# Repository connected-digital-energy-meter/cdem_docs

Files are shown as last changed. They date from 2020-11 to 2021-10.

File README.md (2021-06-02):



# Connected Digital Energy Meter

Connected Digital Energy Meter documentation for the PWO project IoT opportunities.

## Development

First time use:

```bash
npm install
```

To run local VuePress instance:

```bash
npm run docs:dev
```

Then navigate to [http://localhost:8080](http://localhost:8080) in your browser.

## Emojis

Find them on [https://emojipedia.org/](https://emojipedia.org/).

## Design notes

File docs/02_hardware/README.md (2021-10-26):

# Hardware

The **CDEM - Connected Digital Energy Meter** device is a standalone PCB that can be directly connected to a Belgian digital electricity meter. It can then read the P1 port of the digital meter and send that information to an MQTT broker.

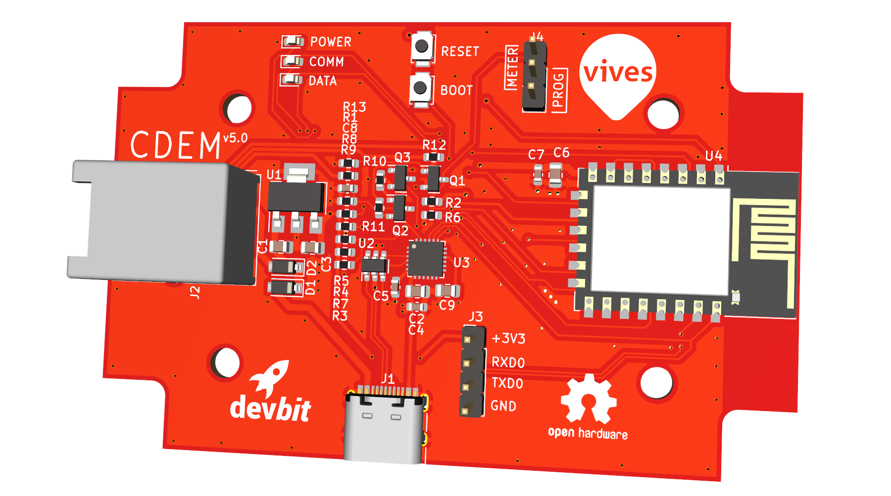
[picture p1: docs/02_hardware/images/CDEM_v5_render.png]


::: tip 🎉 Standalone PCB
The newer versions of the PCB (v4.0 and up) are stand-alone devices and require no external power supply. They draw their energy from the digital meter.
:::

All hardware is open source and can be modified to fit your own needs. Feel free to download the [KiCad project files](https://github.com/connected-digital-energy-meter/cdem-hardware) at Github.

## Ordering Your Own CDEM

Due to the number of small components we advice you to order an assembled PCB, rather then solder it yourself.

When ordering your PCB you will need to upload the following information:

* Gerber files: [Github](https://github.com/connected-digital-energy-meter/cdem-hardware/tree/master/gerber)
* Bill of Material: [Github](https://github.com/connected-digital-energy-meter/cdem-hardware/tree/master/assembly)

### Suppliers

We can advice the following suppliers :

* [JLCPCB](https://jlcpcb.com/)
<figure class="video_container">
  <iframe src="https://jlcpcb.com/video/place.v2.mp4" frameborder="0" allowfullscreen="true"> </iframe>
</figure>
* [ALLPCB](https://www.allpcb.com/)
* [PCBWay](https://www.pcbway.com/)

## RJ12 Cable

Connecting the Connected Digital Energy Meter to the Fluvius Digital meter requires an RJ12 cable with 6 internal wires.

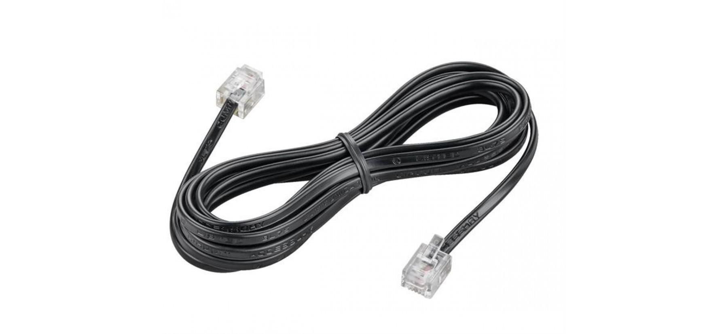
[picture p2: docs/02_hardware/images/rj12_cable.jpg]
RJ12 Cable


When ordering cables one of the cheapest distributors with the wides range of products is [AlleKabels](https://www.allekabels.nl/rj12-kabel/7400/1181351/telefoonkabel-rj12.html). You can choose the length according to your setup.

::: warning 🕵️ Check Connections
Make sure that the RJ12 cable has 6 wires and that both sides have the wires in the same order.
:::

## Casing

To safely take your Connected Digital Energy Meter in operation we recommend putting it into a decent casing. This protects the PCB from dust and such and also makes sure the electronics cannot be short circuited by accident.

A case that fits is the [1591XXM from HAMMOND](http://www.hammondmfg.com/pdf/1591XXM.pdf).

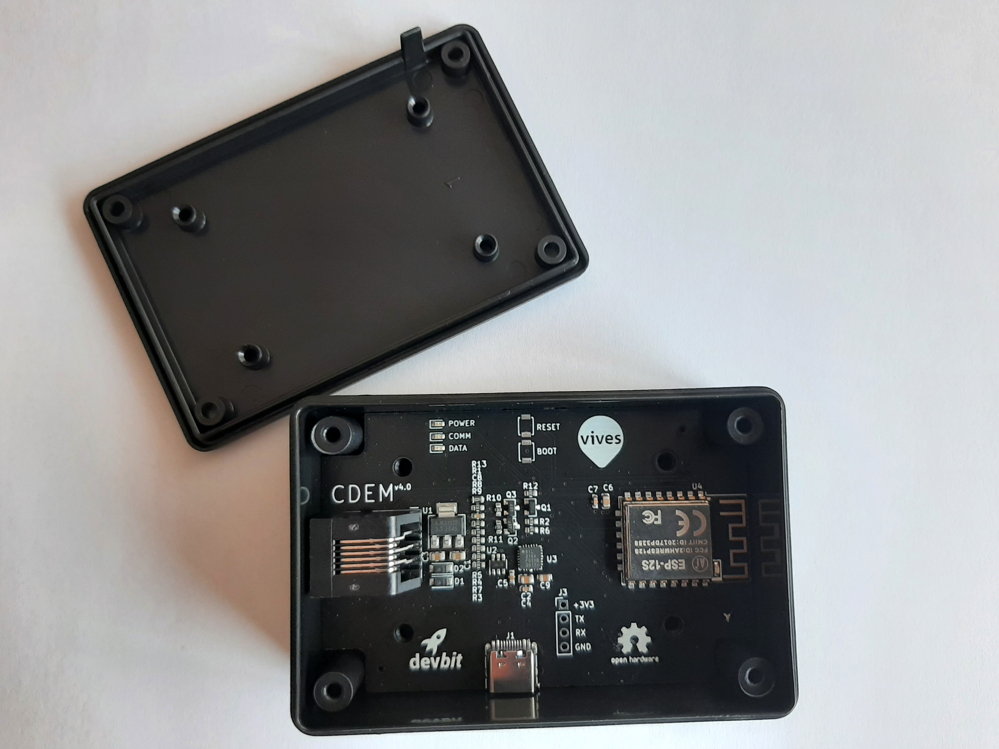
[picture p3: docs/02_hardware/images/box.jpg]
Casing


<!-- TODO - Photo of latest PCB inside case -->

You can order this case on [Conrad](https://www.conrad.be/p/hammond-electronics-1591xxmsbk-1591xxmsbk-universele-behuizing-85-x-56-x-25-abs-zwart-1-stuks-485622).

You will need to make a small adjustment to the box. A small opening will need to be made in the box for the RJ12 connector. You can do this using a small saw or cutter.

<!-- TODO - Photo of latest PCB inside case with cut hole on side -->

If you wish you can mount the PCB inside the case using 4 small 1/4" self-tapping screws, but it is not a requirement.

### 3D Printing Case

If you have a 3D printer at your disposal you can also 3D print your own case.

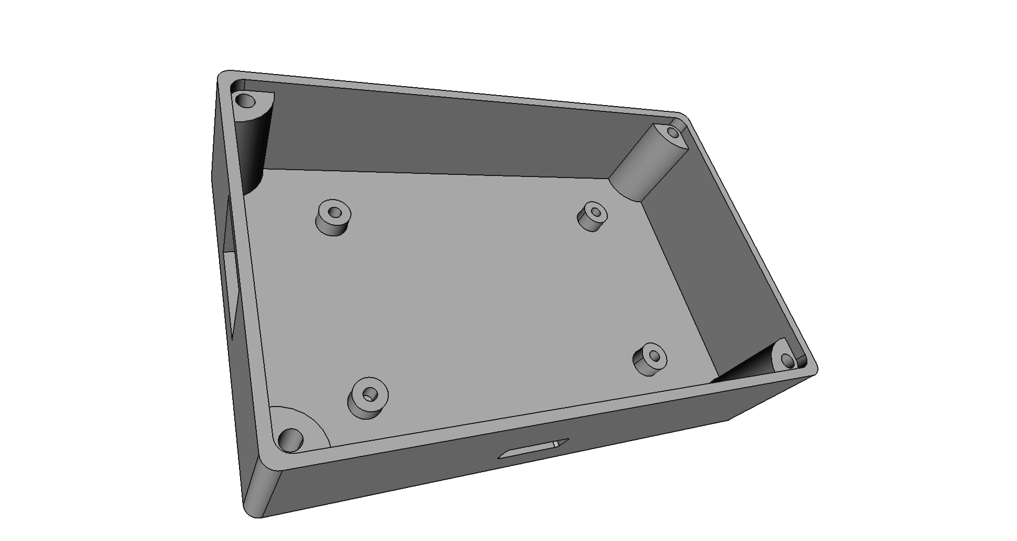
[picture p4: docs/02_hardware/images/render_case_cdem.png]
Render CDEM Case


[CDEM - Casing](https://github.com/connected-digital-energy-meter/cdem-case) is a [FreeCAD](https://freecadweb.org) drawing that contains a basic case which can be easily 3D printed. Feel free to alter it as you wish.

<!-- TODO - Picture of our case -->

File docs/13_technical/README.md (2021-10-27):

# Technical information

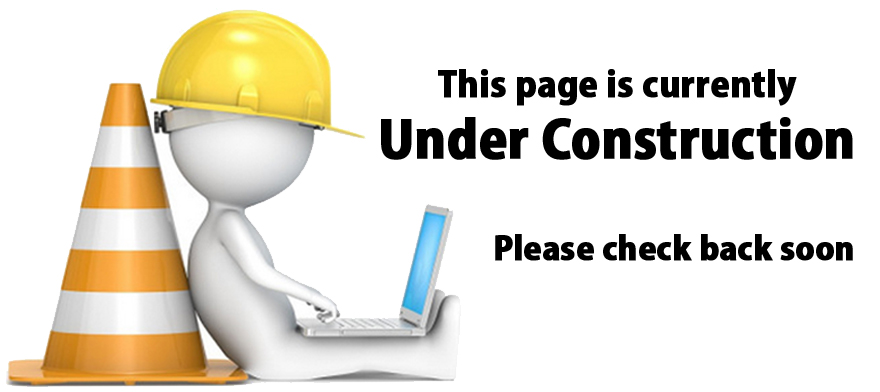
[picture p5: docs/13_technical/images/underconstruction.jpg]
UNDER CONSTRUCTION


## What information is provided with the P1 port ?

The P1 port follows the [DSMR 5 standard](/files/dsmr5.pdf) of the Dutch Smart Meter, extended with the [e-Mucs specification](/files/emucs.pdf).

::: tip S1 Port
The Fluvius digital meter also has an S1 port. This user port (S1) is designed to provide "raw" data to an application (CEMS) at a particularly high frequency. The application must further process this "raw" data to make advanced calculations allowing for very detailed consumption feedback and control.
:::

### Physical connection

The `P1` port is a serial interface that uses a standard RJ12 connector.

::: tip RJ11 vs RJ12
The only difference between RJ11 and RJ12 is in how they are wired and the number of the wires that are being used. RJ12 is a 6P6C wiring standard. RJ11 is a 6P4C wiring standard and only has four wires connected and the remaining two slots are no longer used.
:::

For the CDEM device we need a **RJ12 cable** because we use the digital meter as power source.

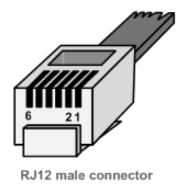
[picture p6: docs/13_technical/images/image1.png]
RJ12 Pinout


| Pin | Signal name |
| :---: | --- |
| 1 | + 5V (Power supply) |
| 2 | Data request |
| 3 | Data GND (ground) |
| 4 | Not connected |
| 5 | Data |
| 6 | GND (ground) |

**Safety**

In order to protect both the user and the Fluvius digital meter, the `P1` port is galvanically isolated from the mains.

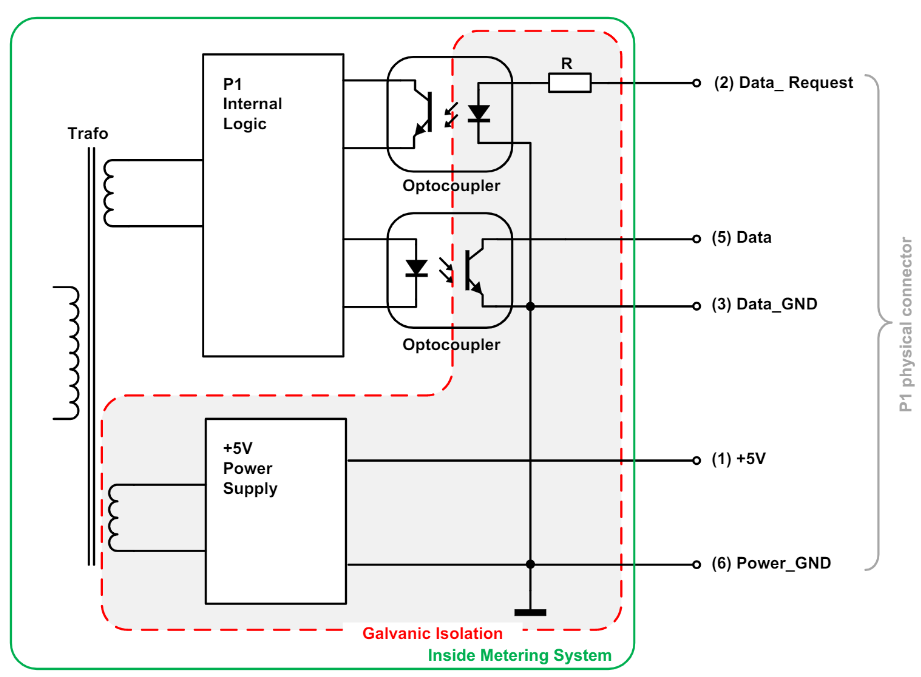
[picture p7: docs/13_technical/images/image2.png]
Port Schematic


#### Power supply

The `P1` interface provides a stable `+5V DC` power supply via `pin 1` (5V) and `pin 6` (GND) to provide a connected IoT device with a power source.

U = 5,0 V ( max = 5,5 V with I = 0 mA , min = 4,9 V with I = 250 mA )

Here we run into our first problem. The maximum output for the power supply is 250 mA which is at the limit for booting a ESP12 chipset.

#### Data request

The P1 port is activated (will start sending data) by setting "Data request" (pin 2) high (4,0V to 5,5V). While receiving data, this line must be kept high.

::: warning Warning
To stop receiving data the "Data request" line must be put in a high impedance mode and must not be connected to the GND or 0V
:::

#### Data

Here we run into our second problem. Due to the use of opto couplers, the "Data" (pin 5) line must be designed as an **Open Collector** output and must be **logically inverted** before it can be used with IoT device ( Raspberry Pi, ESP12, Arduino, ...).

A "Data" line LOW has a voltage of 0,2 V (0 - 1V), HIGH has a voltage of 5,0V with a maximum current of 30 mA.

The solution is either to use a pre-made cable like for instance [this one](https://www.sossolutions.nl/slimme-meter-kabel), or to provide the signal inversion yourself.

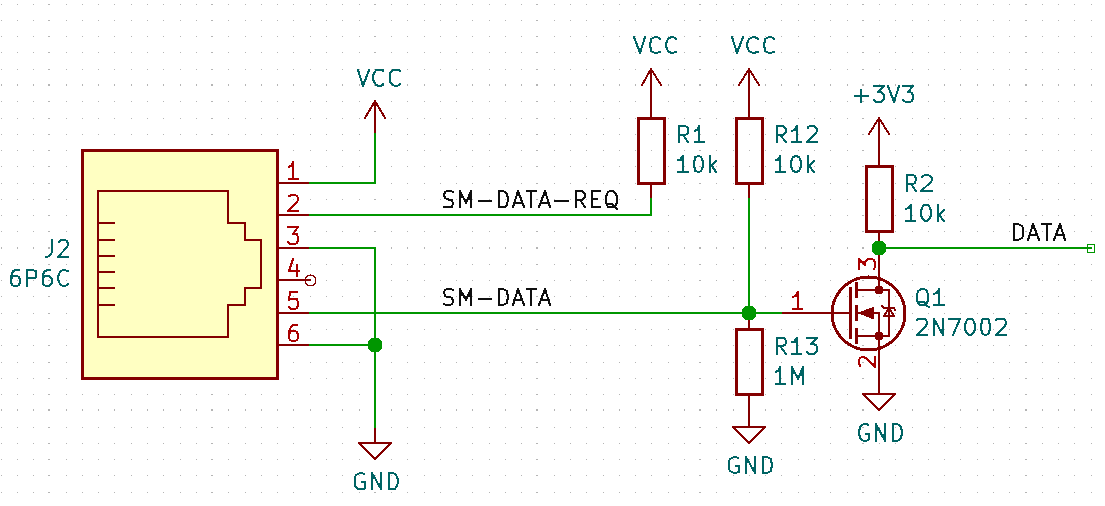
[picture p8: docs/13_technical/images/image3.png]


### Communication protocol

Here we run into our third problem. The P1 communication protocol of a Fluvius Smart Meter is based on the DSMR 5 standard used in the Netherlands but extended with the e-Mucs specifications. Therefore all solutions found on the internet for the Netherlands are not applicable for the Fluvius Smart Meter.

#### Transfert speed and character formatting

The interface must use a fixed transfer speed of 115200 baud. 

::: warning ❗ Cable length restriction
Due to the 115200 baud-rate the max. cable length for this serial communication is 2,5 m.
:::

The Fluvius Smart Meter sends its data to the connected IoT device every single second and the transmission of the entire P1 telegram is completed within 1s.

The format of transmitted data is defined as “8N1”. Namely:

- 1 start bit,
- 8 data bits,
- no parity bit and
- 1 stop bit.

#### Data readout

The Fluvius Smart Meter transmits the data message, as described below, immediately following the activation through the Request signal.



#### End of transmission

The data transmission is complete after the data message has been transmitted. An acknowledgement signal is not provided for.

#### Data objects

For more information on the OBIS codes see the [DSMR 5 standard](/files/dsmr5.pdf) and [e-Mucs specification](/files/emucs.pdf).

##### Electricity data

| OBIS reference | Value | Example |
|---|---|---|
| 0-0:96.1.1 | Equipment identifier | 0-0:96.1.1(4B384547303034303436333935353037) |
| 1-0:1.8.1 | Meter Reading electricity consumption (normal tariff) in 0,001 kWh | 1-0:1.8.1(123456.789*kWh) |
| 1-0:1.8.2 | Meter Reading electricity consumption (low tariff) in 0,001 kWh | 1-0:1.8.2(123456.789*kWh) |
| 1-0:2.8.1 | Meter Reading electricity injected (normal tariff) in 0,001 kWh | 1-0:2.8.1(123456.789*kWh) |
| 1-0:2.8.2 | Meter Reading electricity injected (low tariff) in 0,001 kWh | 1-0:2.8.2(123456.789*kWh) |
| 0-0:96.14.0 | Tariff indicator electricity. **(1=normal, 2=low)** | 0-0:96.14.0(0002) |
| 1-0:1.7.0 | Actual electricity power consumption in 1 Watt resolution | 1-0:1.7.0(01.193*kW) |
| 1-0:2.7.0 | Actual electricity power injected in 1 Watt resolution | 1-0:2.7.0(00.000*kW) |
| 0-0:96.7.21 | Number of power failures in any phases | 0-0:96.7.21(00004) |
| 0-0:96.7. 9 | Number of long power failures in any phases | 0-0:96.7.9(00002) |
| 1-0:99:97.0 | Power failure event log | 1-0:99.97.0(2)(0-0:96.7.19)(101208152415W)(0000000240*s)(101208151004W)(0000000301*s) |
| 1-0:32.32.0 | Number of voltage sags in phase L1 | 1-0:32.32.0(00002) |
| 1-0:52.32.0 | Number of voltage sags in phase L2 | 1-0:52.32.0(00001) |
| 1-0:72.32.0 | Number of voltage sags in phase L3 | 1-0:72.32.0(00000) |
| 1-0:32.36.0 | Number of voltage swells in phase L1 | 1-0:32.36.0(00000) |
| 1-0:52.36.0 | Number of voltage swells in phase L2 | 1-0:52.36.0(00003) |
| 1-0:72.36.0 | Number of voltage swells in phase L3 | 1-0:72.36.0(00000) |
| 1-0:32.7.0 | Instantaneous voltage L1 | 1-0:32.7.0(220.1*V) |
| 1-0:52.7.0 | Instantaneous voltage L2 | 1-0:52.7.0(220.2*V) |
| 1-0:72.7.0 | Instantaneous voltage L3 | 1-0:72.7.0(220.3*V) |
| 1-0:31.7.0 | Instantaneous current L1 | 1-0:31.7.0(001*A) |
| 1-0:51.7.0 | Instantaneous current L2 | 1-0:51.7.0(002*A) |
| 1-0:71.7.0 | Instantaneous current L3 | 1-0:71.7.0(003*A) |
| 1-0:21.7.0 | Instantaneous active power consumption L1 | 1-0:21.7.0(01.111*kW) |
| 1-0:41.7.0 | Instantaneous active power consumption L2 | 1-0:41.7.0(02.222*kW) |
| 1-0:61.7.0 | Instantaneous active power consumption L3 | 1-0:61.7.0(03.333*kW) |
| 1-0:22.7.0 | Instantaneous active power injected L1 | 1-0:22.7.0(04.444*kW) |
| 1-0:42.7.0 | Instantaneous active power injected L2 | 1-0:42.7.0(05.555*kW) |
| 1-0:62.7.0 | Instantaneous active power injected L3 | 1-0:62.7.0(06.666*kW) |
| 0-0:96.3.10 | Breaker state | 0-0:96.3.10(1) |
| 0-0:17.0.0 | Limiter treshold | 0-0:17.0.0(123.4*kW) |
| 1-0:31.4.0 | Fuse supervision threshold (L1) | 1-0:31.4.0(001*A) |

::: warning 🔥 Belgian vs Dutch meter
The Obis-references for High and Low tarif are switched for the Belgian meter compared to the Dutch meter!
**(1 = normal tarif , 2 = low tarif)**
:::

##### Messages

| OBIS reference | Value | Example |
|---|---|---|
| 0-0:96.1.4 | Version information | 0-0:96.1.4(50) |
| 0-0:96.13.0 | Text message max 1024 characters. | 0:96.13.0(303132333435363738393A3B3C3D3E3F3031) |
| 0-0:96.13.1 | Consumer message code | 0-0:96.13.1(3031203631203831) |

##### Gas data

| OBIS reference | Value | Example |
|---|---|---|
| 0-n:24.1.0 | Device-Type | 0-1:24.1.0(003) |
| 0-n:96.1.0 | Equipment identifier | 0-1:96.1.0(3232323241424344313233343536373839) |
| 0-n:24.2.1 | Last 5-minute value (temperature converted), gas delivered to client in m3, including decimal values and capture time | 0-1:24.2.1(101209112500W)(12785.123*m3) |
| 0-n:96.1.1 | M-Bus Device ID 2 |  0-1:96.1.1(3232323241424344313233343536373839) |
| 0-n:24.4.0 | Valve state | 0-1:24.4.0(1) |
| 0-n:24.2.3 | Last value of ‘not temperature corrected’ gas volume in m³, including decimal values and capture time | 0-1:24.2.3(101209112500W)(12785.123*m3) | 

##### Thermal data

| OBIS reference | Value | Example |
|---|---|---|
| 0-n:24.1.0 | Device-Type | 0-1:24.1.0(003) |
| 0-n:96.1.0 | Equipment identifier | 0-1:96.1.0(3232323241424344313233343536373839) |
|  0-n:24.2.1 | Last 5-minute Meter reading Heat or Cold in 0,01 GJ and capture time | 0-1:24.2.1(12.34*GJ) |

##### Water data

| OBIS reference | Value | Example |
|---|---|---|
| 0-n:24.1.0 | Device-Type | 0-1:24.1.0(003) |
| 0-n:96.1.0 | Equipment identifier | 0-1:96.1.0(3232323241424344313233343536373839) |
| 0-n:24.2.1 | Last 5-minute Meter reading in 0,001m3 and capture time | 0-1:24.2.1(12785.123*m3) |

::: warning 🔥 Warning
Be aware of the fact that the number of OBIS codes and the order of them is not fixed. Therefore the connected IoT device must be able to interpret the P1 telegram.
:::

## How is the hardware build ? 

### Version 1

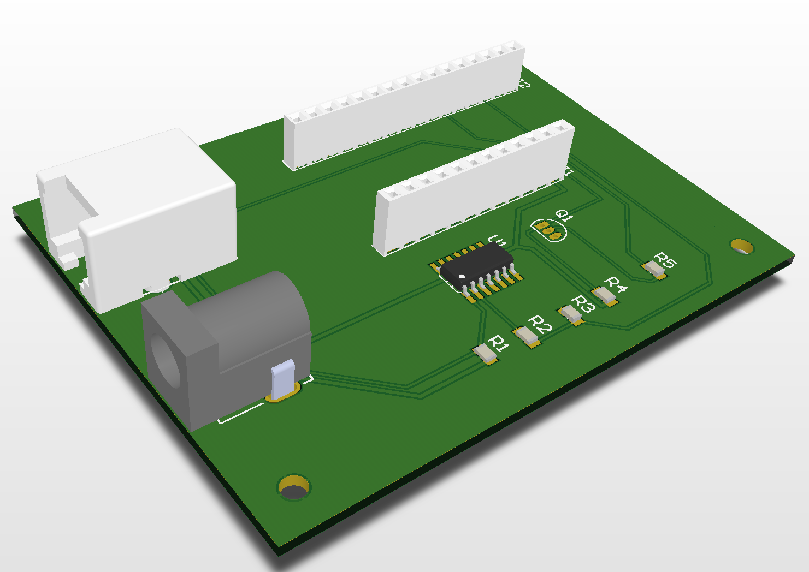
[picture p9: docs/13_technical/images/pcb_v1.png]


This is our [first prototype model](https://workspace.circuitmaker.com/Projects/Details/RonnyMees/FluviusMeterv1) to establish proof of concept, being able to read the P1 telegram from the Fluvius Digital Meter.

This pcb works in conjunction with the [Feather Huzzah 32](https://learn.adafruit.com/adafruit-huzzah32-esp32-feather).

### Version 2

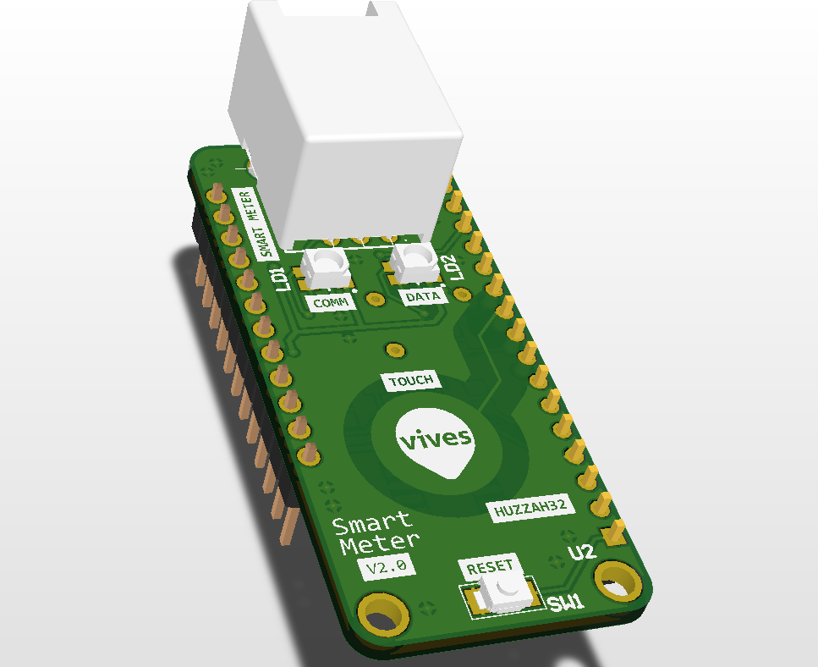
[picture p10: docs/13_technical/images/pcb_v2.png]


This is our [second prototype model](https://workspace.circuitmaker.com/Projects/Details/Nico-De-Witte/cdem) to establish proof of concept, provide a fully functional device that reads the P1 telegram from the Fluvius Digital Meter and publishes it toe a MQTT broker.

This pcb works in conjunction with the [Feather Huzzah 32](https://learn.adafruit.com/adafruit-huzzah32-esp32-feather).

### Version 3

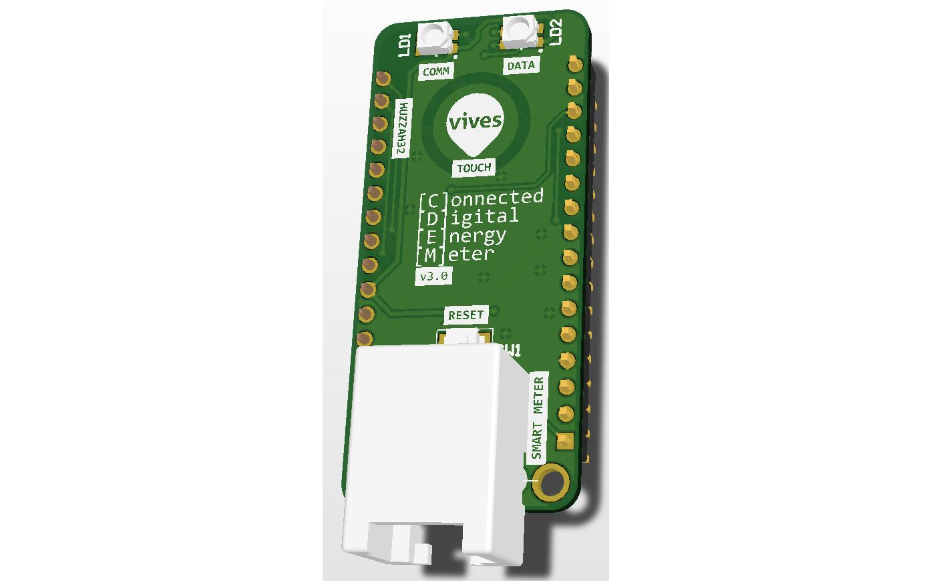
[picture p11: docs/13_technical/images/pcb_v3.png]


In the previous version the usb connector and the RJ12 connector where on opposite sides, therefore we made a [third prototype model]() that was a mirrored version of the second version. This model was never made.

This pcb works in conjunction with the [Feather Huzzah 32](https://learn.adafruit.com/adafruit-huzzah32-esp32-feather).

### Version 4

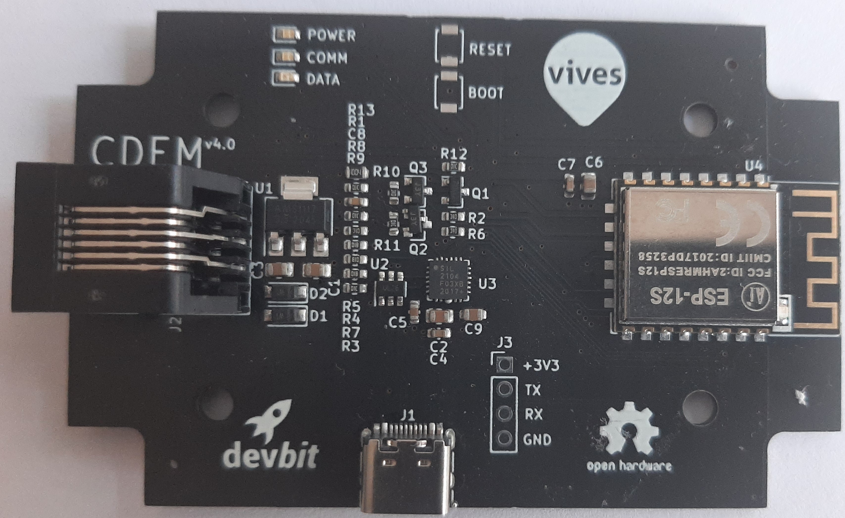
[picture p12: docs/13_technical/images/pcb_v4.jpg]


During a meeting with Fluvius we decided to build a new version that could work standalone (with the power provided by the Fluvius Digital Meter). Due to the powerlimitations we had to rethink our concept and look for low power consuming components to be able to build that [fourth prototype model](https://github.com/connected-digital-energy-meter/cdem-hardware).

### Version 5

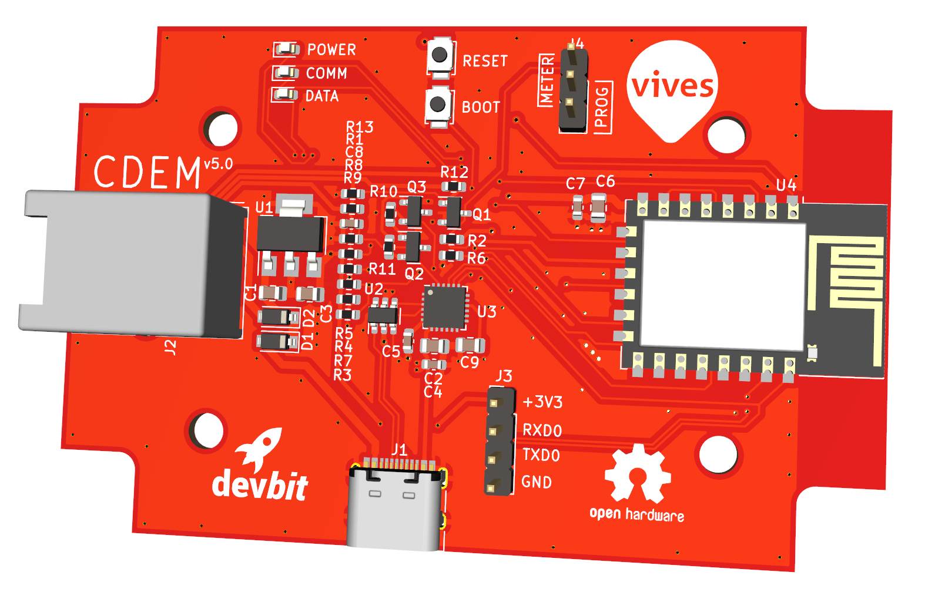
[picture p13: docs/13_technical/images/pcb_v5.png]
PCB v5


<!-- TODO : Github link toevoegen -->
Due to some power issue's and a fault we discoverd in the previous prototype we made a final version that solves this issue.

For the production version we provide some build information of the pcb.

**1. Connection to the Fluvius Meter**



We use the power supply provided from the Fluvius Meter (pin 1). The maximum output is 250 mA which is at the limit of what we need for our ESP12.
:::danger 🔌 Limited Power supply
Should your CDEM experience power problems and reboots often, then we advice to use an external USB power supply.
:::

**2. USB connection and UART bridge**

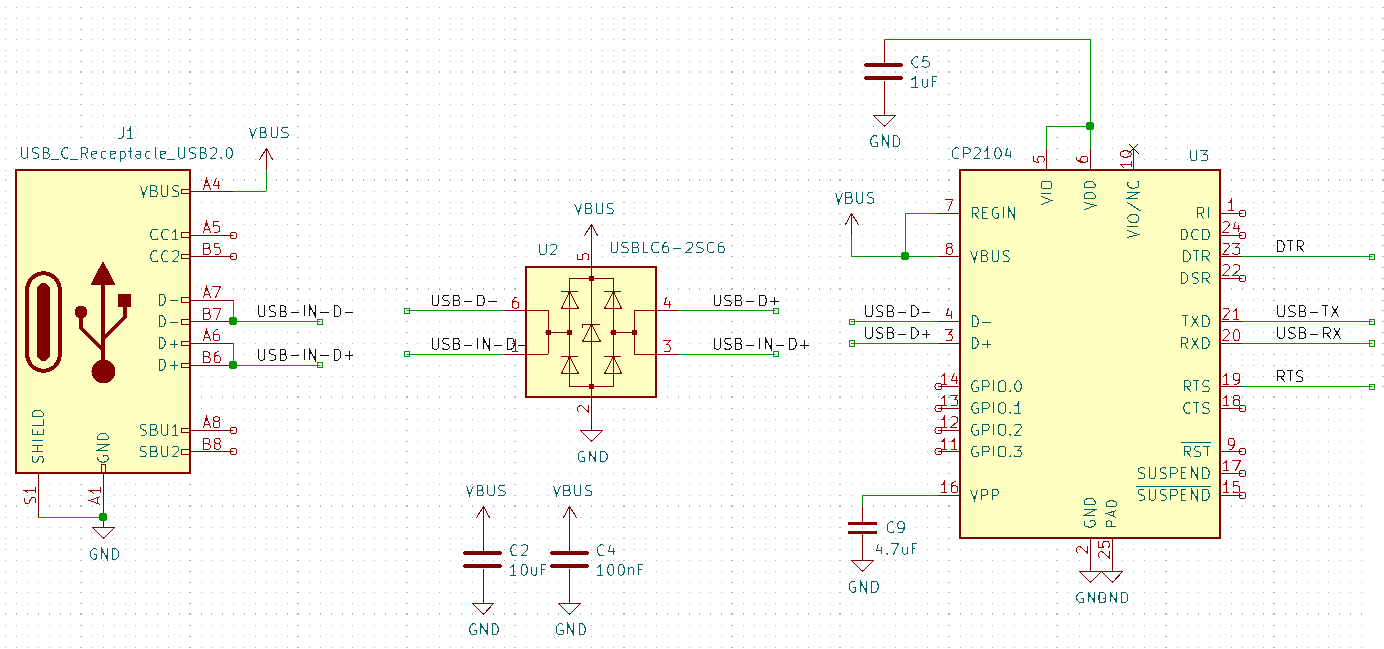
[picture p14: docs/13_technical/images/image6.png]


We have provided a usb connection on the PCB in order to be able to load the firmware via a UART bridge and provide a external power supply if necessary.

**3. Voltage regulator 5V to 3.3V**

<!--TODO: dit moet mogelijks nog aangepast worden naar een nieuwe versie -->

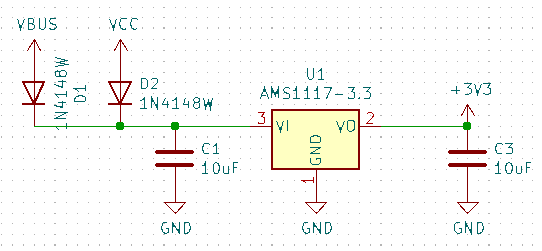
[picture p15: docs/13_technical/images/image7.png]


We have provided a voltage regulator that provides the board of 3.3V.

**4. Processor**

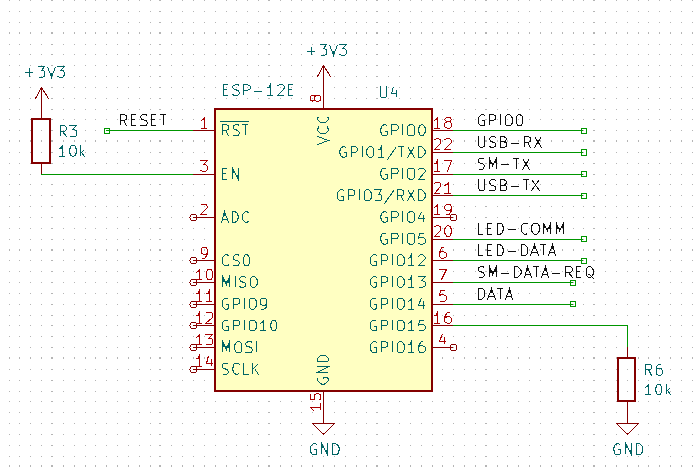
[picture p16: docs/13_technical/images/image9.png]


The heart of the board is a ESP-12E chipset that provides us with a processor and wifi module.

**5. Extra**

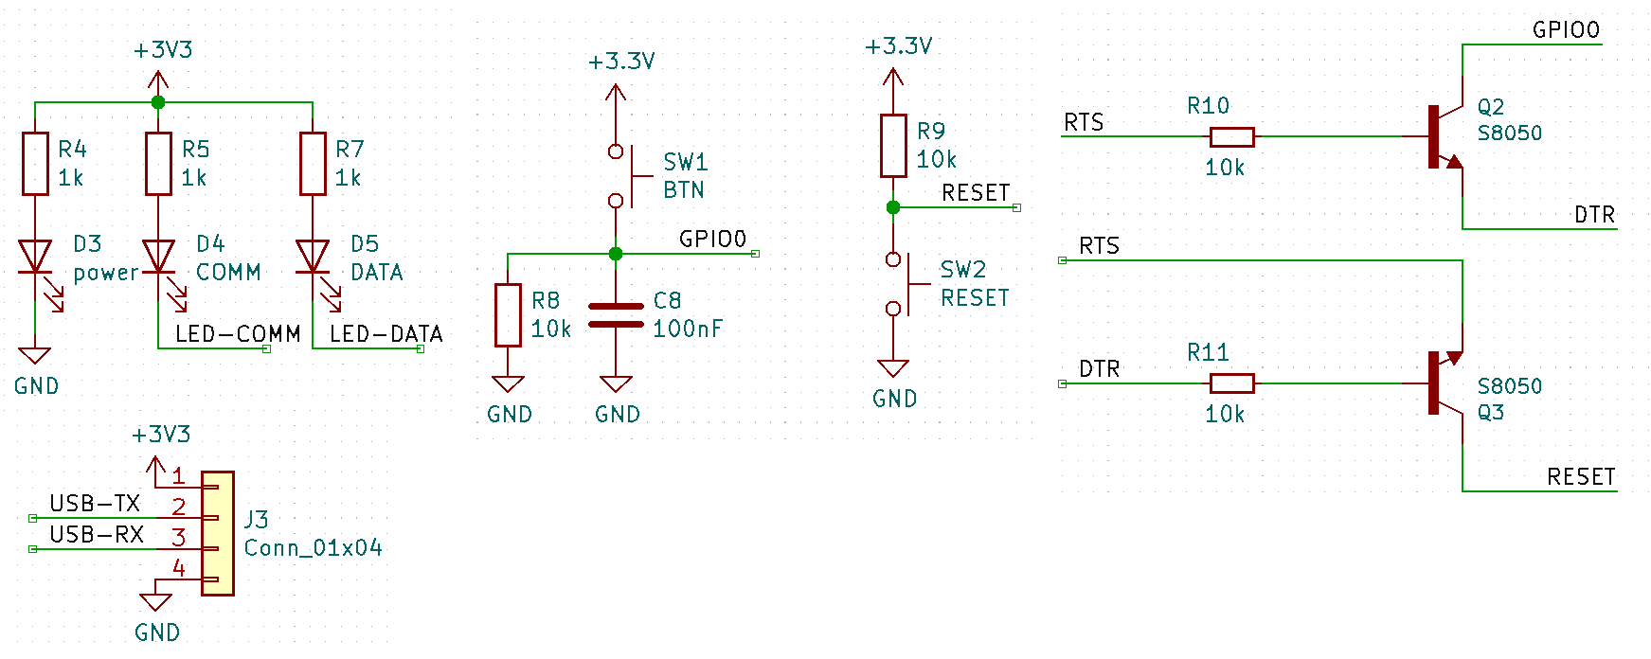
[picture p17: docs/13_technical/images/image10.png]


Finaly we also provided some small circuits for communication led's, push buttons and a jumper.

## How is the firmware build ? 

<!-- TODO: Hier komt de onwikkelinfo van de firmware -->

This flowchart explains the program structure of the firmware.

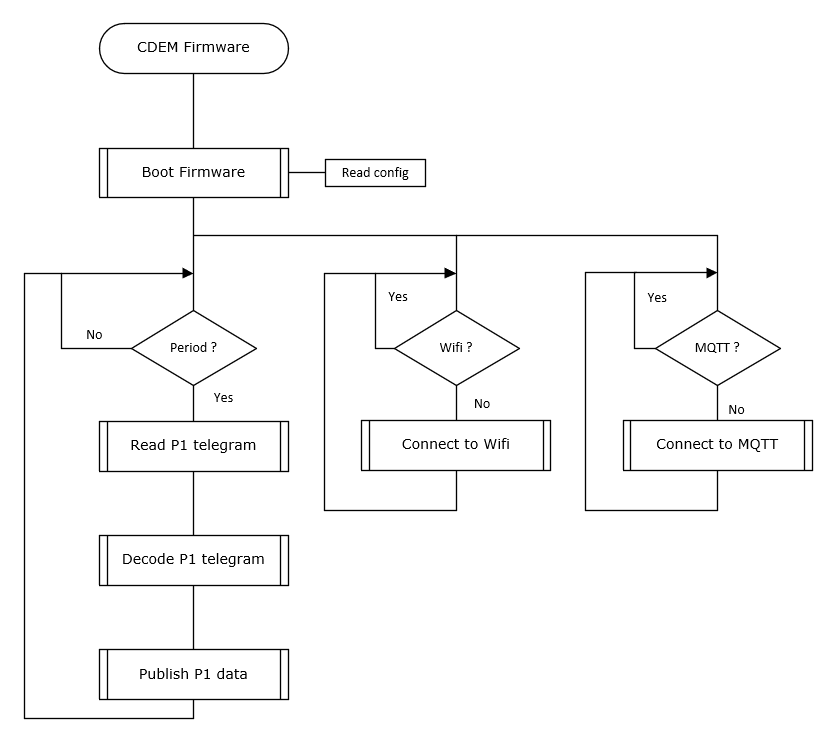
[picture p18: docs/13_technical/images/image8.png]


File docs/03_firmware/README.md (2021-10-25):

# Firmware

Now that you have your CDEM PCB, it is time to upload the firmware into the ESP12 chipset.

Connect the PCB to your computer using a USB-C cable and follow the guide below to flash the device with the latest firmware.

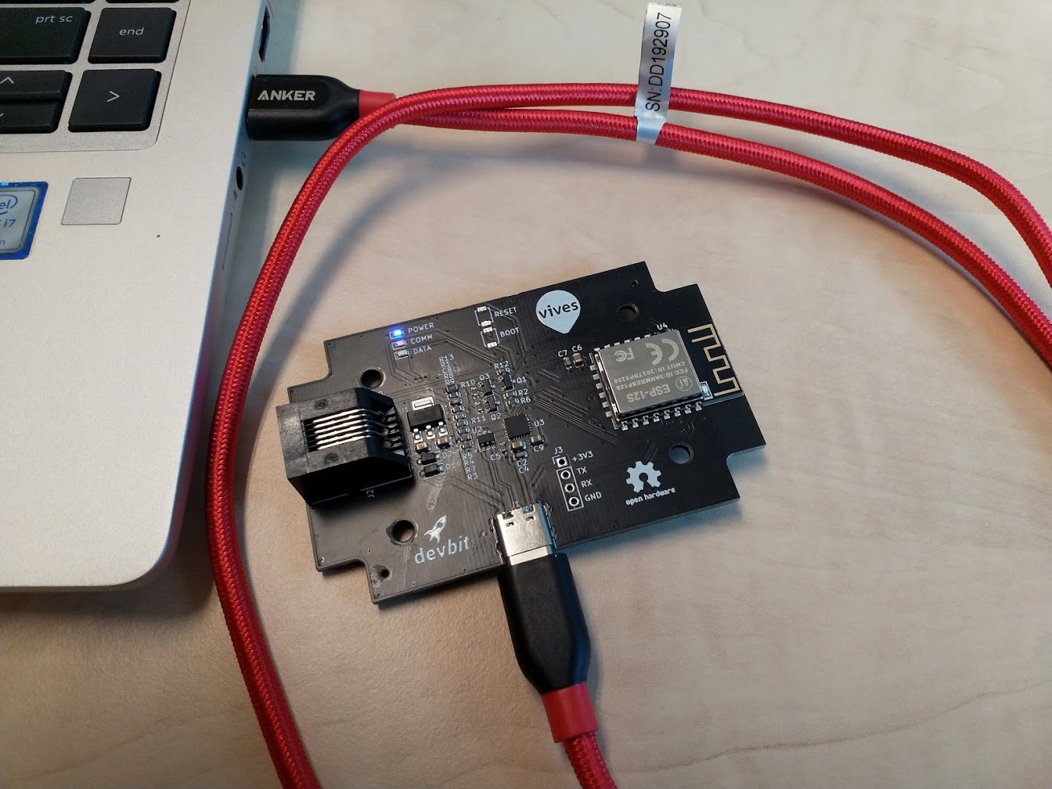
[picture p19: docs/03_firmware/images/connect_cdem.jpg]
Connect CDEM


## Install Arduino IDE

In order to compile and flash the firmware for your CDEM device, you will need to install Arduino IDE.

Instructions on how to install this IDE for most operating systems can be found on the website of [Arduino](https://www.arduino.cc/en/Guide) itself.

Once installed, start the IDE to continue.

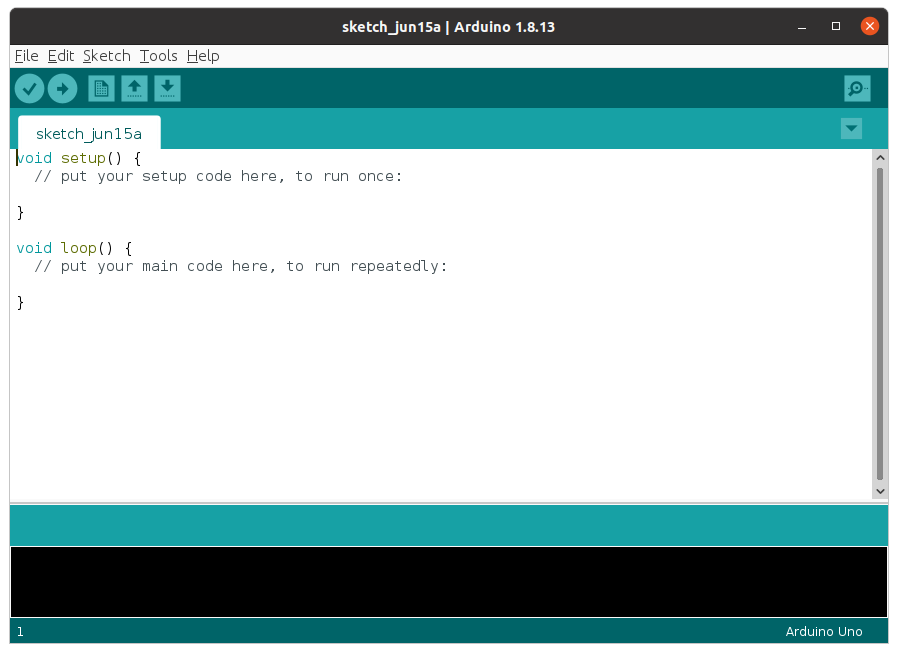
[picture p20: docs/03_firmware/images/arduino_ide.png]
Arduino IDE


## Install ESP12 Board Package and Tools

Before any applications can be compiled for the ESP12, the board support package and tools need to be installed.

Navigate to `File => Preferences` and add the stable release link `http://arduino.esp8266.com/stable/package_esp8266com_index.json` to the **Additional Boards Manager URLs**. Multiple URLs can be added by clicking the small window icon next to the input field and using one URL per line.

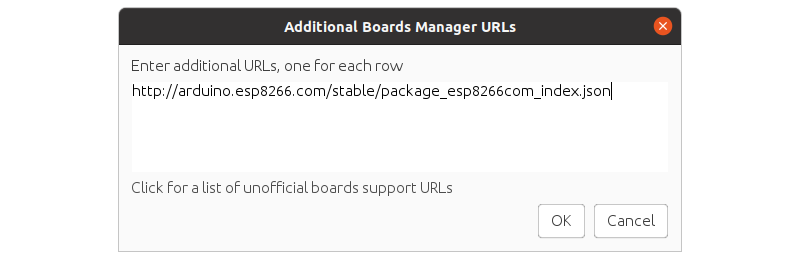
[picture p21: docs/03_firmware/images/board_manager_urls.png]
Board Manager URLs


Open `Tools => Board => Board Manager ...` and search for `esp8266`. Next install the `esp8266 by Community` (the CDEM firmware is tested with v3.0.0).

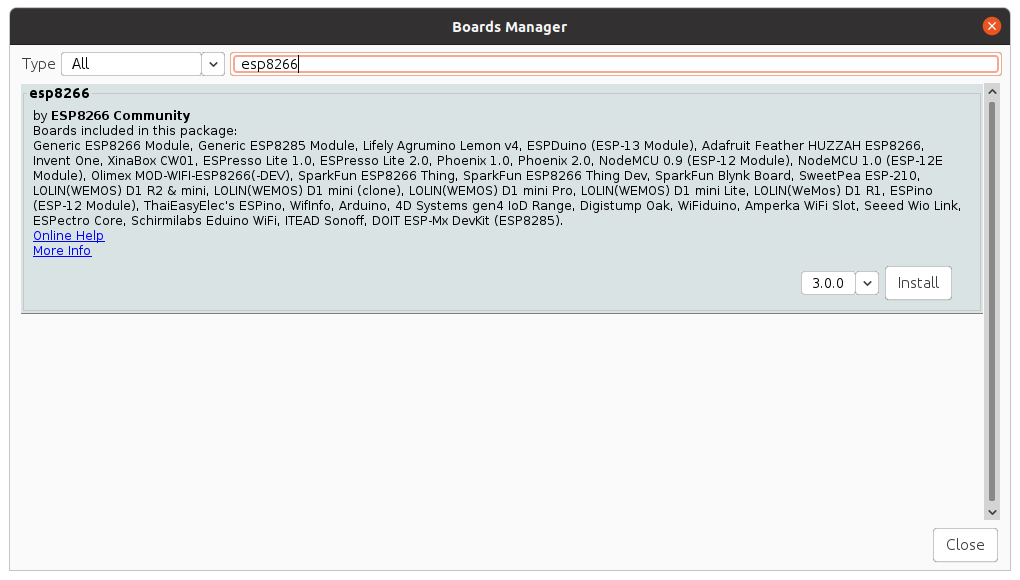
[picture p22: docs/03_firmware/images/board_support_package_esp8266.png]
Install BSP


## Download the Latest Firmware

Download the latest firmware for the ESP12 from the [CDEM Firmware GitHub page](https://github.com/connected-digital-energy-meter/cdem-firmware/releases).

::: tip Latest Firmware
Make sure to download the latest firmware so you are up-to-date with the latest changes.

Note that the `v1.x` releases targeted the old hardware (using ESP32) while the newer `v2.x` and up releases target the standalone ESP12 system (PCB v4.0 and up).

For more information on the versions see our [Technical information](/13_technical/#how-is-the-hardware-build).
:::

Under `Assets` you will find the source code ZIP file. Download this file to your local system.

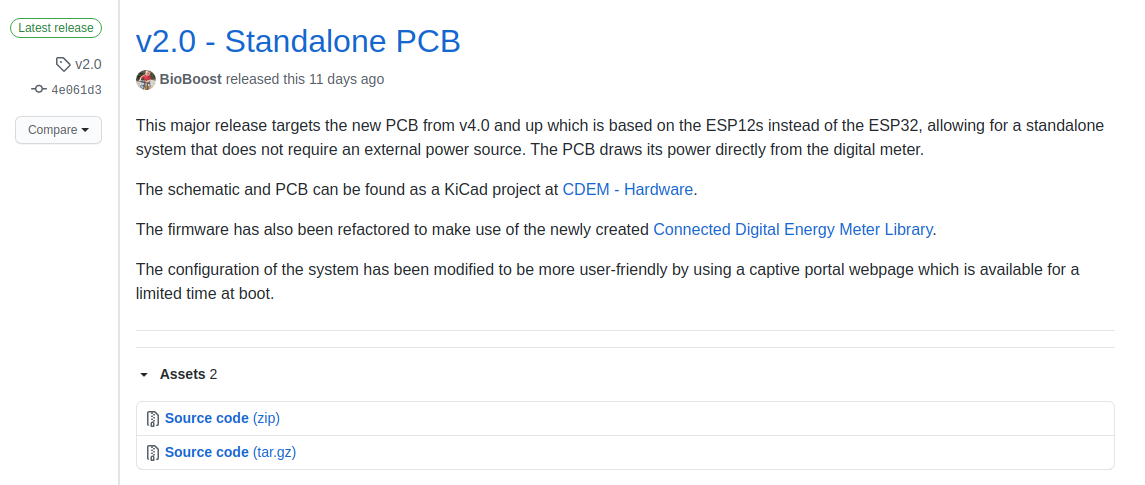
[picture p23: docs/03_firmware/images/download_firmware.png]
Firmware


Extract the ZIP file somewhere on your system.

::: tip 🐑 Git Clone
You can also clone the project using GIT if you are familiar with it. That way you can easily pull new updates from our code repository.

To clone the project just execute the command `git clone https://github.com/connected-digital-energy-meter/cdem-firmware.git` somewhere you wish to store the project.
:::

Open Arduino IDE and traverse to the location you extracted the ZIP file. Select the project and open it.

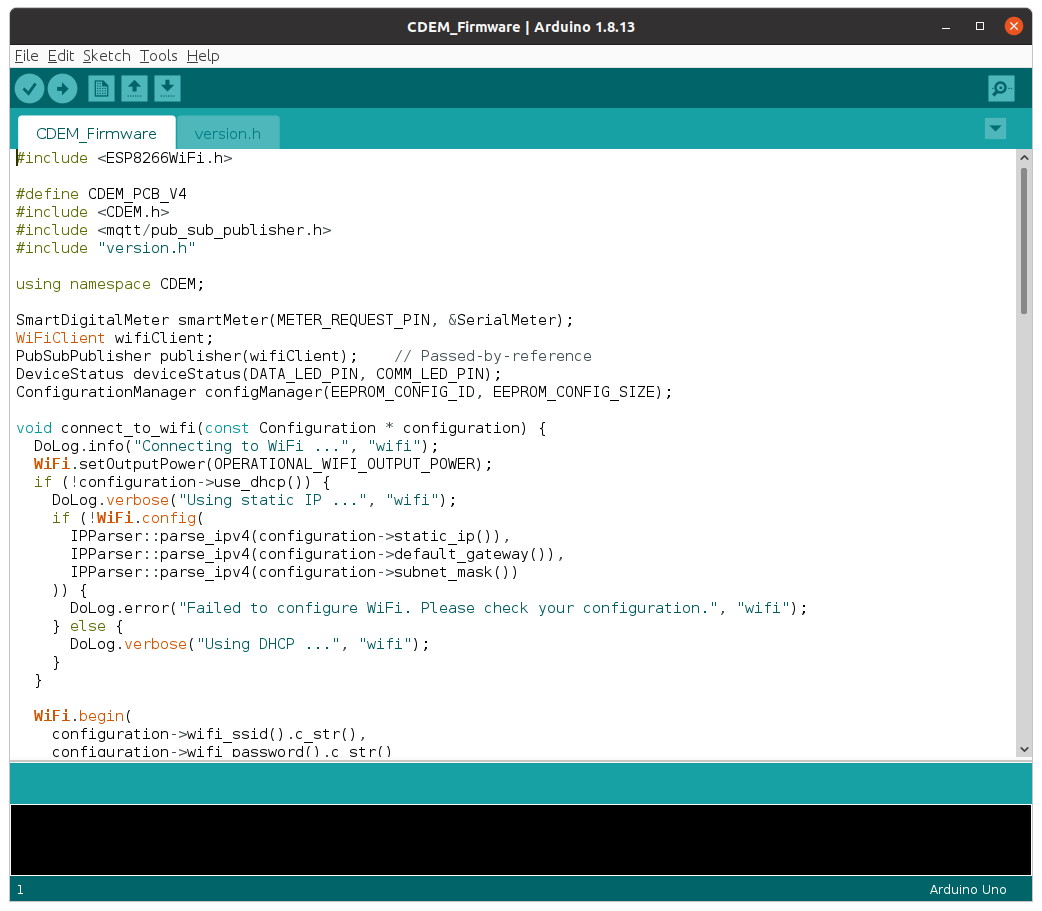
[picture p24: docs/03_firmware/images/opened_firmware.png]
Opened Firmware


Now select the `Generic ESP8266 Module` board from the `Tools => Board => ESP8266 Boards` menu after installation. Select the correct `COM-port` from `Tools => Port` (make sure the device is connected to your computer).

Next you will be required to install the different libraries the firmware depends on to do its work.

## Installing the Required Libraries

Several libraries have to be installed in order for the firmware to be compiled. The following sections describe how each library can be installed.

::: tip 😺 Git
If you are familiar with git you can also clone the library repositories in your user home directory under `Arduino/libraries` and checkout the required release tags. The `Arduino/libraries` path is automatically included when the project is compiled.
:::

### The CDEM Library

The firmware for the ESP12 module you downloaded is only the tip of the iceberg. Most of the functionality of the firmware is provided by the `Connected Digital Energy Meter` library.

Download the latest release of the [Connected Digital Energy Meter library](https://github.com/connected-digital-energy-meter/connected-digital-energy-meter/releases) as a zip file to your local system.

CDEM Library Latest Release

Make sure that you have opened the firmware project in the Arduino IDE. Next include the CDEM library via `Sketch => Include Library => Add ZIP Library ...`.

### The PubSubClient Library

PubSubClient is a client library for MQTT messaging.

1. Open the Arduino Library Manager via `Tools => Manage Libraries`
2. Search for `PubSubClient` (make sure to use the library by **Nick O'Leary**)
3. Select the version: `2.8.0`
4. Click install.

PubSubClient

::: warning 🚨 Other MQTT Libraries
There are a lot of other MQTT libraries out there and each has its pitfalls. PubSubClient is one of the most mature which is still being maintained.
:::

### The ArduinoJson Library

The ArduinoJson library allows easy parsing and conversion of JSON strings. The full payload of all the meter telemetry is transmitted as JSON.

1. Open the Arduino Library Manager via `Tools => Manage Libraries`
2. Search for `ArduinoJson` (make sure to use the library by **Benoit Blanchon**)
3. Select the version: `6.18.0`
4. Click install.

ArduinoJson

## Compile and Upload the Firmware

Make sure your CDEM is connected to your host PC via USB and that the correct port is selected.

Before trying to upload your firmware to your CDEM device, make sure that the jumper is in the programming position as shown in the next image.

Program Jumper

Select the Upload button and watch the magic happen. If all went well you should get similar output to that shown below.

Successful Compilation

After a couple of seconds the device should start to output messages to the serial monitor.

Serial Monitor

The green communication LED on the board should start to blink with an interval of about 2 seconds. This means that the device has put up a WiFi access point and is awaiting configuration.

Captive Portal

Don't forget to put back the jumper into the meter position after uploading the firmware or the device will not be able to read the data from the meter later on.

Program Jumper On

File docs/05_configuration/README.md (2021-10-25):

# Configuring your CDEM

Upon the first startup of the firmware, the factory default settings are loaded. These default settings need to be altered to suit your own home network configuration before the device will function correctly.

::: warning ✋ Configuration is Mandatory
In its initial state, the device will not boot past the point of setting up the access point. This because your network information is required, before the datagrams can be published to an MQTT broker. This is also a preliminary safety measure to protect your data and make sure you as an owner of the device have taken the time to configure the device.
:::

The device will at least require the following information:

* Your WiFi SSID
* Your WiFi password
* An MQTT broker IP address

::: tip 🌐 No Internet required
The device does not access the Internet in any way unless you are using a public MQTT broker. No information is send to any third party and no information is fetched for any purposes. The device also does not allow any external connection to be made to the device itself, except for the configuration procedure at boot.
:::

## Accessing the Configuration Page

Make sure you have the CDEM device connected to your host computer using a USB-C cable.

::: warning 🔌 More power
In some cases the CDEM device will draw a bit more power than allowed by the Fluvius digital meter when configuring the device (as it sets up a WiFi access point). Because of this we recommend connecting the device to a computer via USB or using a smartphone power adapter when configuring the device.
:::

Connecting the CDEM Device

The device can be configured by connecting to the access point provided by the device on boot-up using a smartphone or computer. This access point will only be **available for a limited time of 5 minutes**. If the configuration page is not accessed within the time window the device will boot using its current configuration.

To connect to the access point, reboot the device by disconnecting and connecting it back to the power supply. Once the **COMM LED** blinks green with an interval of about 2 seconds, the access point should be available.

<!-- TODO - Animated gif of blinking comm led -->

Captive Portal Status

Use the information below to connect to the access point:

* **WiFi SSID:** `CDEM-Config`
* **WiFi Password:** `smartmeter`

Access Point

Make sure to disable your data connection as it will interfere with connecting to the configuration page of the CDEM device.

You should now be able to open a browser and navigate to the configuration page located by entering almost any URL in the location bar of your browser. Best is to enter a URL you have not visited previously as your smartphone may not send a DNS request for that but use its cache. Take for example [config.cdem.be](http://config.cdem.be).
.

Or you can scan the QR code below which will connect using the IP address.

QR Code Configuration Page

If the connection to the configuration page fails to load, check your connection to the access point. If for some reason the connection is lost, you may need to reboot the device as the 5 minute window may have passed.

Once the configuration page is loaded, you have all the time in the world to complete the configuration as the access point will be kept operational until you reboot the device or save the configuration.

<!-- TODO - Take new screenshot with default configuration -->

Config Page

## Configuring the Device

To configure the device, just alter the current settings. All settings are validated before they are saved to the internal device memory.

<!-- TODO - Bricked device => reflash -->

### Network Settings

The first configuration parameters involve your **network settings**. This is required so the device can connect to your local network and therefore to the MQTT broker. The device does not make any attempt to the connect to the Internet unless you use a public external broker, which is highly discouraged.

Your password is also saved inside the device and will never be made public. It is only used by the device itself. No services are running on the CDEM device that allow incoming connections except for the configuration portal.

WiFi Configuration

Next you will be able to select to **use DHCP or not**. If not, you will need to provide a static IP address, subnet mask and default gateway for your network communication. Since no communication to the CDEM device is required, we encourage you to use DHCP and allow your router in your home network to supply a dynamic IP address.

Static IP

### MQTT Settings

Next you will need to configure your MQTT broker IP-address, port and base topic.

The IP address of your broker is the IP address of the device your broker is running on (NAS, server, Raspberry Pi, ...).

In most cases the port should be left to it's default of `1883` unless you configured the broker to use another port.

The base topic can any topic you choose. Topics can be hierarchical and sub-topics can be separated from each other using forward slashes `/`. Just make sure not to end or start your topic with a forward slash. Also document the topic somewhere, as you will need it later on.

MQTT Settings

### Meter Settings

Last but not least can change how often you wish to publish the meter data. This can range from `1` second to `3600` seconds. The quicker you publish the data, the more granular your graphs will be able to display the data. However, it will also require more data storage. A good value is every `30` seconds.

Meter Settings

### Saving

Once you are satisfied with your configuration, you can save the settings in the memory of the device by clicking the `Save` button.

If all goes well, the device will save the settings and continue the boot process.

Success Page

## Altering the Configuration

Changing the device settings can be done at any point. All you need to do is:

1. Connect the device to a computer of smartphone adapter.
2. Reboot the device.
3. Connect to the access point `CDEM-Config` with the password `smartmeter`.
4. Traverse to the configuration page by accessing some url like [config.cdem.be](http://config.cdem.be)
5. Alter the configuration settings.
6. Save the settings using `Save` or discard the changes using `Cancel`.

::: warning 🏭 Factory Default
If you ever lend the device or give it to someone else, make sure to reset the device to its factory default settings. This can be achieved by accessing the configuration portal and hitting the `Factory Defaults` button.
:::

## Configuration Settings Reference

* **WiFi SSID**: The SSID (Service Set IDentifier) of an access point in your local home network that the CDEM device can use to connect to your network and MQTT broker.

* **WiFi password**: The password to connect to your local network.

* **Use DHCP or not**: If you use DHCP (Dynamic Host Configuration Protocol) the CDEM device gets it's network settings automatically from your router/access point. If you want to configure those settings yourself, don't use DHCP.

* **Static IP**: The IP address you want your CDEM device to use in your network. Check your network configuration before assigning this so you do not create conflicts with other network devices.

* **Subnet Mask**: The subnet mask for the device to use in case you assign it a static IP address.

* **Default gateway**: The IP address to use as a default gateway. This should be the internal IP address of your local router.

* **MQTT broker IP Address**: This is the IP Address of the MQTT broker the CDEM device should use to publish your data to.

* **MQTT broker port**: This is the port used to communicate with the MQTT broker. Usually this is port `1883`.

* **MQTT broker base topic**: Your meter data is published to a topic on the MQTT broker. The topic can use some hierarchical levels by separating sub-topics using a forward slash. Different devices usually publish their data on different topics. The factory default for the base topic is `iot/myhome/cdem`.

* **Read Period**: The device will periodically read the data from the P1 port and publish it to the selected MQTT broker. The time between different reads can be configured between `1` and `3600` seconds.

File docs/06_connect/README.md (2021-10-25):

# Connecting your CDEM

Connecting the CDEM device to the utility meter is extremely easy. All you need is a 6-wired RJ12 cable. Plug one side in the meter and the other in the CDEM device. Once your digital meter user ports have been activated, the data of the meter can be retrieved with the CDEM device.

<!-- TODO - Image of a connected cdem device here -->

## Activating the Fluvius Meter Port

Before the data of the Fluvius digital meter can be read out, one has to activate the P1 port of the meter online (no technician is required). This can be achieved by requesting an online activation at the [Fluvius website](https://www.fluvius.be/nl/thema/meters-en-meterstanden/activeer-desactiveer-je-gebruikerspoorten).

You will need the following in order to make your request:

* your ID card
* a card reader or [itsme](https://www.itsme.be/) to login
* a recent energy invoice of your current supplier

After filling in the online form, the activation process can take up to several days. If your meter has just been placed, you should wait a couple of days before making this request to make sure that the meter is registered with Fluvius.

Once the activation process has been completed, your digital meter will start to send its telemetry data via the S1 and P1 ports. Do note that the meter itself does not send its data to the cloud or any other service. However, if ever required, the P1 port can be deactivated using the same online form.

::: tip ⌚ Can take some time
The actual meter activation process can take up to **72 hours**. Normally you should receive an email from Fluvius when the process is finished and the ports have become available.
:::

Once the user ports have been activated, it should be indicated by a small arrow above the `GP` on the digital meter. If not, than your user ports are not yet activated.

Active User Ports

## Connecting to the Fluvius meter

Use the RJ12 cable to connect your Digital Energy Meter device to the Fluvius digital meter.

RJ12

::: warning 📞 Straight Cable
Do make sure you have a straight cable and not a crossover cable. You can check this by holding both connectors next to each other in the same orientation and checking if the wire-coloring is the same on both sides.
:::

Connect to the **P1 port** of the digital meter (the right hand one when standing in front of the meter). **The S1 port will not work.**



Your CDEM device will immediately start booting as it draws it's power from the Fluvius digital meter. This is indicated by the power LED on the CDEM device lighting up blue.

[Device Operation](/07_operation) provides detailed information about the status LEDs and all the different states the device operates in.

## Mounting your CDEM

It's a good idea to protect the CDEM device from dust and accidental touching by enclosing it within a small case. Using some double sided tape, also allows you to attach the casing to the side of your Fluvius digital meter.

<!-- TODO - Full setup photo -->

<!-- TODO - Add casing here ? -->

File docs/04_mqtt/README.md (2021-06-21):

# MQTT

MQTT is one of the most commonly used protocols for Internet of Things devices to communicate with each other. MQTT stands for Message Queuing Telemetry Transport. It is a very lightweight messaging protocol that uses a **publish / subscribe** mechanism to exchange data between different clients. It is small in size, low in power consumption and uses minimized data packages, ideal for machine-to-machine communication and therefor for the Internet of Things.

MQTT Logo

## An Example

Lets consider the situation where we have temperature sensor that want to share its current data with other devices. On the other hand we have devices such as a smartphone or computer who want to receive this data to process it or display it in a dashboard.

To transport this data across devices, MQTT can be used in conjunction with a centralized service called the broker.

The data supplier will setup a connection with the broker and publish its data on what is called a **topic**, which is basically an identifier for the data.

Other services/devices that are interested in this particular data can then also connect to the same broker and **subscribe** on this topic, allowing them to receive the data.

MQTT - Source: https://www.eclipse.org/community/eclipse_newsletter/2014/october/article2.php

So basically there are two things that happen:

* The sensor specifies a **topic** under which it will **publish** its data. For example `temperature`. Then it will publish its temperature value to this topic.
* Anyone who wants to receive the data can then **subscribe** to the topic `temperature`. Every time the sensor publishes new data, all subscribers are automatically notified of the new temperature value.

## How does CDEM use MQTT ?

The CDEM devices basically does the same thing as the aforementioned temperature sensor. It reads the energy data from the digital meter and publishes that data to an MQTT broker.

From that point on any other interested services (Home Assistant, openHAB, NodeRED, ...) can access the data. This of course within your own home network if you are not using a public broker (which we discourage anyway).

## Installing an MQTT broker service

Before taking your CDEM in operation you have to provide a MQTT broker service in your local network.

[Mosquitto](https://mosquitto.org) is one of the brokers that can be used to communicate with MQTT. It's a simple and lightweight broker, and is available on many different platforms (Docker, Raspberry Pi, standalone, NAS, ...).

::: warning 🌍 Public Brokers
While its perfectly viable to use a publicly available broker such as `mqtt.eclipse.org` or `broker.hivemq.com`, we strongly discourage this approach as you will be sending your personal sensitive data to a public and open broker.
:::

### Linux Based Installation - Debian alike

If you have a Raspberry Pi with a Debian based system (Raspbian, Ubuntu, ...) or a Linux based server available in your network, the installation of Mosquitto is a walk in the park.

Installing Mosquitto on any Linux Debian based system is super easy. Just update your local package repositories and install the `mosquitto` package. For a basic setup such as ours, no further configuration is required.

```bash
sudo apt update
sudo apt install mosquitto
```

::: warning 💻 Static IP
Do make sure to install the Mosquitto broker on a system with a static or MAC-reserved IP address. It should not change otherwise the CDEM device will be unable to connect to the broker.
:::

### NAS System

Most NAS (Network Attached Storage) systems such as synology allow you to install services such as Mosquitto by the click of a button.

Since there are many systems out there we cannot provide a manual for each. However, it should not be too hard to find some information on the Internet on how to install an MQTT broker on your NAS.

### Docker

While docker is not a host device on its own, many systems (Linux Servers, NAS-systems, ...) allow easy deployment of docker containers.

If you have a docker environment on any of your network devices (server, NAS, ...) you can setup a Mosquitto broker by deploying a container of the [eclipse-mosquitto image](https://hub.docker.com/_/eclipse-mosquitto).

### Docker-compose - All in One

For a more advanced [all in one setup](/11_docker_compose) checkout the documentation on using docker-compose.

## Testing your MQTT broker service

Feel free to test your broker using a tool such as [MQTT Explorer](http://mqtt-explorer.com/). It's an MQTT client application that allows you to see all data passing by on your broker as well as allow you to publish messages on a topic.

Once your CDEM device is operational and configured, you should see its data pass by just as shown in the next screenshot.

MQTT Explorer

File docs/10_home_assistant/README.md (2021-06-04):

# Home Assistant

[Home Assistant](https://www.home-assistant.io/) is a open source home automation platform.

In this chapter we will be discribing how to import the MQTT data from your CDEM for displaying and automation purposes.

## Configure your MQTT broker

First you will need to provide the MQTT broker setup in your `configuration.yaml` file:

```yaml
# MQTT broker        
mqtt:
  broker: <your broker IP-adress>
  port: 1883
  client_id: home-assistant
  keepalive: 60
```
## Configure your sensors

Next you will need to add all sensors (the measurements from CDEM available in the MQTT broker).
This can be done in your `configuration.yaml` file or a seperate sensor file.

```yaml
# Consumption low tarif
- platform: mqtt
  name: "Consumption low tarif"
  unit_of_measurement: 'kWh'
  state_topic: "<your base topic>/consumption_low_tarif"
  unique_id: "consumption_low_tarif"
  value_template: "{{ value|float  }}"
```

## Configuring groups

Now that the CDEM information is made available you can visualise it by adding them to your `groups.yaml` file.

```yaml
actual_energy:
    name: Actual Energy
    entities:
      - sensor.tarif
      - sensor.active_voltage_l1
      - sensor.active_current_l1
      - sensor.actual_power_consumption_2
      - sensor.actual_power_production_2
energy_meters:
    name: Energy Meters
    entities:
      - sensor.consumption_low_tarif
      - sensor.consumption_high_tarif
      - sensor.production_low_tarif
      - sensor.production_high_tarif
      - sensor.gas
      - sensor.water
```

The result could be something like this:



## Automations

Next you can start adding some automations to make your home energy consumption better.
This can be done in the `automations.yaml` file.

See chapter [Energy Efficiency](/12_energysavings) for some suggestions on that.

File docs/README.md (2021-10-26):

---
home: true
heroImage: files/CDEM_v5_render.png
tagline: The first steps towards making your digital utility meters smart
actionText: Get Started →
actionLink: /01_introduction/
footer: The PWO project IoT Opportunities is a research project of VIVES University College
---

# IoT Opportunities - Connected Digital Energy Meter

As of July 2019 Fluvius has been installing digital meters all over Flanders. By July 2029, all families and SMEs must have a digital meter[1]. The fact that digital meters will not allow excess produced energy to be credited to the user in the near future has taken a lot of public attention. The next step in the evolution of our Belgian energy system is that as of June 2022 part of the netcost will be calculated based on "peakpower" usage[2]. Basically, users that use a lot of electricity for shorter periods will pay more netcosts than users that spread their energy consumption. Digital utility meters provide services such as automatic passing of meter reading, easy tarif switching, remote connecting and disconnecting from the energy network, automatic firmware upgrades, ...[3] Most importantly digital meters provide insight into a users energy consumption and allow homes to become more integrated and connected to the digital world. However, digital meters also come with serious challenges. Often these devices are labelled as "smart" devices, while at the time of this writing we can barely call them digital, let alone smart. While there are people ahead of the digital curve and have homes that are connected to the Internet of Things in every possible way, users who are less digitally connected often are left behind and never really get to the point where this digital source of information can become useful to them.

Digital Meter

This brings us to the goal of this whole project: "Empower users and provide the tools in an open way so that users can become owners of the information the digital meters are providing. Give people the tools to build the smart solutions for the challenges of today and tomorrow". Start by becoming more conscious about your daily energy usage and/or production. By providing these tools in an open and free way, we also encourage people to build upon them and create solutions for common energy problems.

Our mission is fourfold and consists of the following phases:

1. Provide an open hardware platform to retrieve the user data from the digital meter and make the data available to the user in such a way that it can be visualized, interpreted and processed further without much effort.
2. Visualize the data in such a way that it becomes information for the user and provides insights into his/her daily electrical consumption and/or production.
3. Allow the user to act upon this information and construct solutions that improve their awareness of they handle energy usage.
4. Provide a stepping stone for automating these solutions and build a more digitally connected home.

<!-- FIGUUR! -->

In this project we provide an open hardware system called CDEM, Connected Digital Energy Meter, which allows the data of the digital meters to be readout and published via a common used messaging system called MQTT. Tools such as [Grafana](https://grafana.com/) allow dashboards to be build and provide insight into the raw data coming from the digital meter. By pulling your data in a home automation platform, such as [Home Assistant](https://www.home-assistant.io/) or [OpenHAB](https://www.openhab.org/), the information can be processed and used to take action.

All development information is made available with this documentation, open and free of charge. Our hope is that it gets picked up by the open  community and real-world solutions are built upon this. 

<!-- References -->
[1]: https://www.fluvius.be/nl/thema/meters-en-meterstanden/digitale-meter/wanneer-krijg-ik-een-digitale-meter
[2]: https://www.test-aankoop.be/woning-energie/gas-elektriciteit-mazout-pellets/nieuws/waarom-je-beter-je-stroomverbruik-spreidt-vanaf-2022
[3]: https://www.vlaanderen.be/bouwen-wonen-en-energie/zelf-energie-produceren/zonnepanelen-en-zonneboilers/de-digitale-energiemeter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

## Research Project

**Connected Digital Energy Meter (CDEM)** is part of the PWO project **IoT Opportunities**, a research project of [VIVES University College](https://www.vives.be). The CDEM project is/was developed by:

* Nico De Witte
* Ronny Mees
* Sille Van Landschoot

**IoT Opportunities** is an initiative of [IoT Incubator](https://iot-incubator.be).

## Disclaimer

The use of this website (and of the information contained therein) is done solely at your own risk. The information on the website is general and not tailored to personal or specific  circumstances. The information on the website and its content are not binding. VIVES makes every effort to provide up-to-date and correct information, however it cannot be completely excluded that the content, information and technical documentation may contain  errors.

VIVES shall under no circumstances be held liable by anyone for direct or indirect damage (e.g. injuries, defects or costs) resulting from the use of the information on this website,  or arising from the impossibility of consulting this website, except those caused by gross negligence on the part of VIVES.  The proof of this gross negligence must be provided by the user.

Nor can VIVES be held liable for direct or indirect damage (e.g. injuries, defects or costs) resulting from the use of the content of a third-party website to which it refers.

## License

<br />This work is licensed under a <a rel="license" href="http://creativecommons.org/licenses/by-sa/4.0/">Creative Commons Attribution-ShareAlike 4.0 International License</a>.

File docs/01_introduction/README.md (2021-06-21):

# Introduction

As of July 2019 Fluvius has been installing digital meters and must install at least 80% of the digital meters by December 31, 2024. By July 2029, all families and SMEs must have a digital meter.

Digital Utility Meters

As of January 2021 the constitutional Court has decided these digital meters will not be subtracting produced energy with solar panels from consumed energy from the net. Instead you will need a new contract with your energy supplier for delivery of energy to the net.

Now more then ever it is in everybody's interest to monitor your energy consumption and if possible automate your home for optimal use of energy.

Home automation

This is where the **Connected Digital Energy Meter - CDEM** device comes into play. It allows you to extract your utility meter data from the devices (digital electricity and gas meters) and put it to better use.

Our two main goals are

1. To learn from the data and allow you as a user to adapt your behavior to make optimal use of your energy
2. Make your home smarter and allow your household appliances to make use of the surplus energy at the appropriate time.

In that context we are providing this open source information to building a connected digital energy meter intended to support the do-it-yourself community and manufacturers in reading the data from a P1 port on the Fluvius digital meter. From there on the data is published to an MQTT broker, allowing it to be visualized in a dashboard or even integrated into an (existing) demotics system, making it possible to automate your energy usage at the most appropriate time.

The CDEM system will allow you to **leverage your digital meter into an actual smart meter**.

::: tip 🚀 Activating the P1 port
Before you are able to use the P1 port of your Fluvius smart meter, it has to be **activated**. This process is described in [Connecting to the Fluvius meter](/06_connect).
:::

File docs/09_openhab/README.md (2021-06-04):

# openHAB

<!-- TOTO: Test if this info is correct and complete to setup openHab CDEM info page -->

[openHAB](https://www.openhab.org/) is a open source home automation platform.

In this chapter we will be discribing how to import the MQTT data from your CDEM for displaying and automation purposes.

* First you will want to install a MQTT binding.



* Next you will want to add the MQTT broker to things. This will form a bridge to your MQTT broker.



* Next you will want to add the MQTT binding to things. Use the MQTT broker you previously defined as bridge.



* Next you will want to add the channels (these are the topics of your broker) to that MQTT binding. Select the previous made MQTT binding and go to the tab 'channels'. Now Add a channel for each value you want to use in openHAB. 



* Once a channel has been added you will need to link a item to it. Just select the channel and click 'Add link to Item'. Next click 'Item to Link' and select the correct item.



* Next you will be able to add the information to a existing or new [page](https://www.openhab.org/docs/ui/sitemaps.html).



The result could look like this:



Of course is visualisation of the energy value's only the first step in energy effeciency.
The next step will be to use that data to make your home energy consumption better.

See chapter [Energy Efficiency](/12_energysavings) for some suggestions on that.

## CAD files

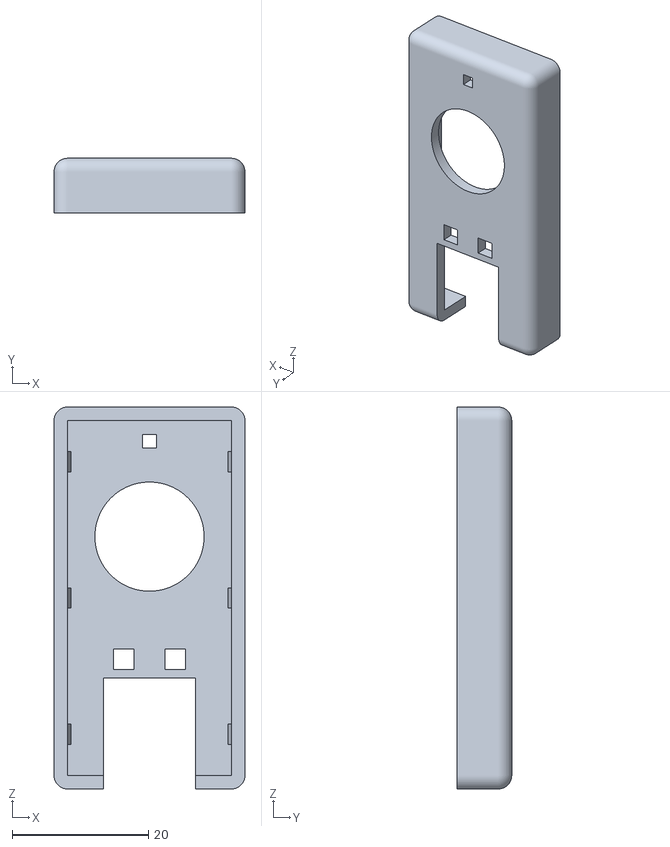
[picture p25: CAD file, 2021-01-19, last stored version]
docs/.vuepress/public/files/top.stl
28.0 x 8.00 x 56.0

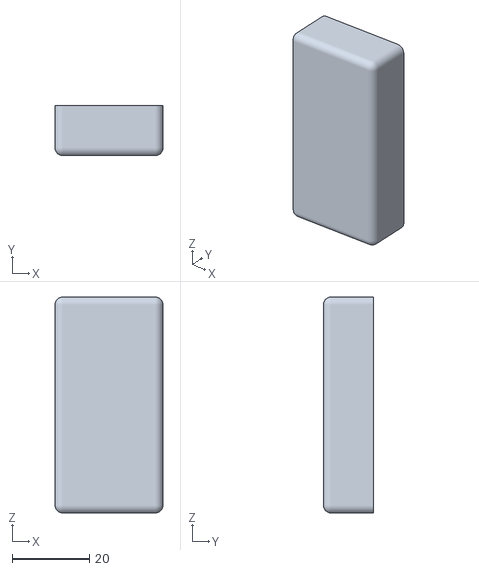
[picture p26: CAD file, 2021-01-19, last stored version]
docs/.vuepress/public/files/bottom.stl
28.0 x 13.0 x 56.0

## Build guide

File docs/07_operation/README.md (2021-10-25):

# Device Operation

The CDEM device is equipped with three status LEDs (power, comm and data) next to the RJ12 connector. These LEDs indicate what the device status is at all times and should provide the user with some basic feedback.

<!-- TODO - Update to v5 PCB -->

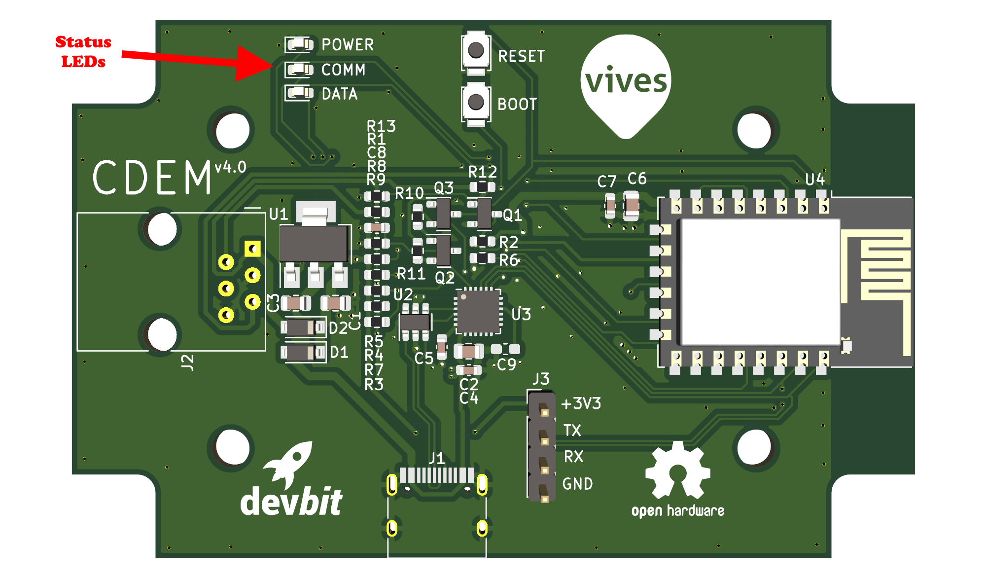
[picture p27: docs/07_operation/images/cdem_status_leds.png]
CDEM Status LEDs


The following sections describe the different steps in the boot process and operational modes with their corresponding status LEDs.

## A Powered CDEM Device

Once your CDEM device is powered, the **power** LED will light up solid blue. This LED should be on during operation.

<!-- TODO: Change image to power led on  -->
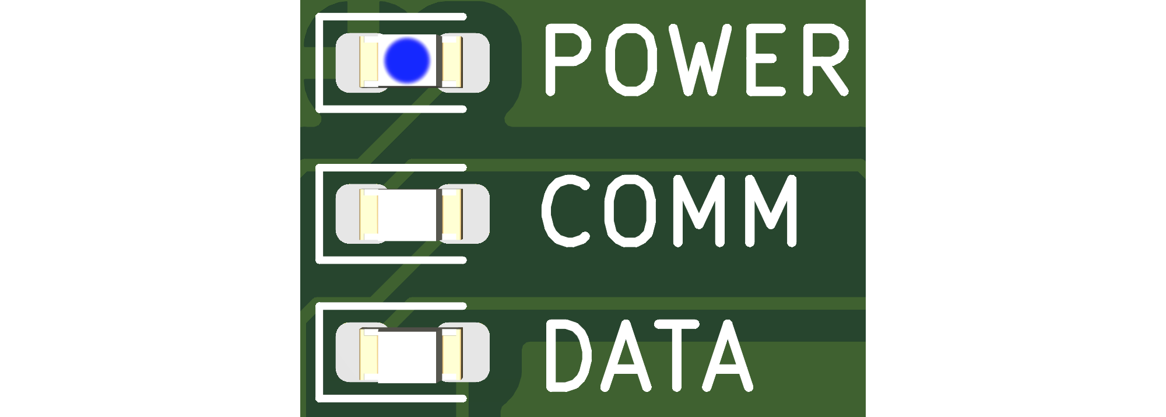
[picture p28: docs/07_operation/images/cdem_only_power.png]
Power LED on


::: danger 💡 Power Issue
If the power LED is on continuously when the device is plugged into the digital meter, there might be a power or the device might be faulty. Disconnect the device immediately and check the [Troubleshooting](/15_troubleshooting) section for more information.
:::

## The Boot Process

Immediately after applying power, the CDEM device will start the boot process.

Then the device will setup a configuration access point for about 5 minutes. This is indicated by the green communication LED blinking slowly (interval of about 2 seconds). You can either connect to the device and select the 'Boot without Saving' option from the configuration page or wait 5 minutes for the portal window to pass.

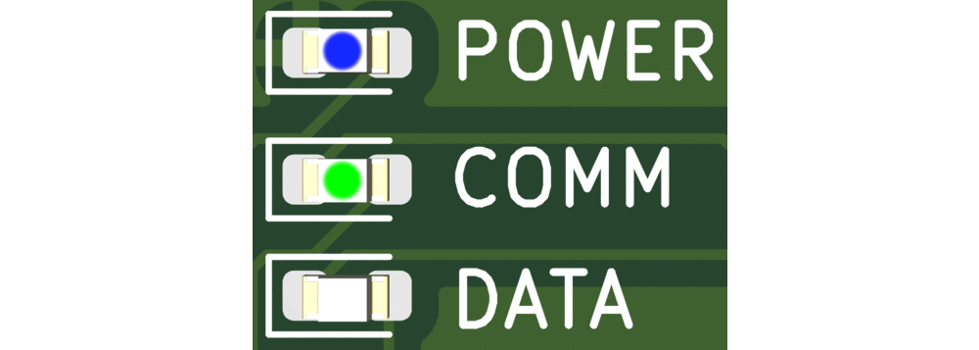
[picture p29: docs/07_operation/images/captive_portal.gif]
CDEM Captive Portal


### Default Configuration

If the device has not been configured properly, it will not boot past the point of setting up the access point. This because your network information is required, before the datagrams can be published to an MQTT broker. This is also a preliminary safety measure to protect your data and make sure you as an owner of the device have taken the time to configure the device. This state will be indicated by the two LEDs (data and comm) blinking alternately (a police light as it were). Checkout the [Configuring your CDEM](/05_configuration) section for more information on how to configure the device properly.

CDEM Default Config

## Communication Status

Once the device configuration has been validated, the device will continue the boot process by trying to connect to the WiFi network. As long as no WiFi connection could be established, the data LED will be off.

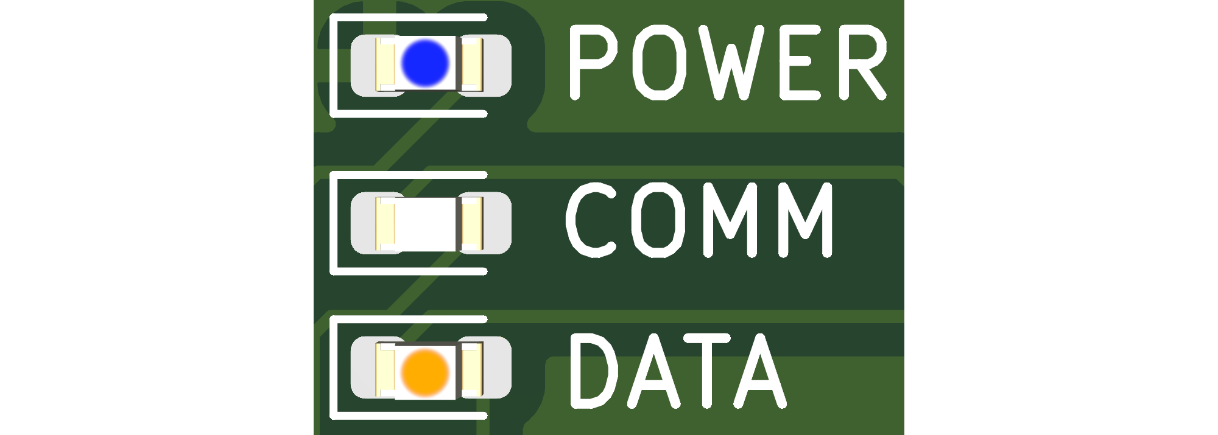
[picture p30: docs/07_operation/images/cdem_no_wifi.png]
CDEM No WiFi


The moment an active WiFi connection can be established, the **data LED will flash quickly** while trying to **connect to the broker**.

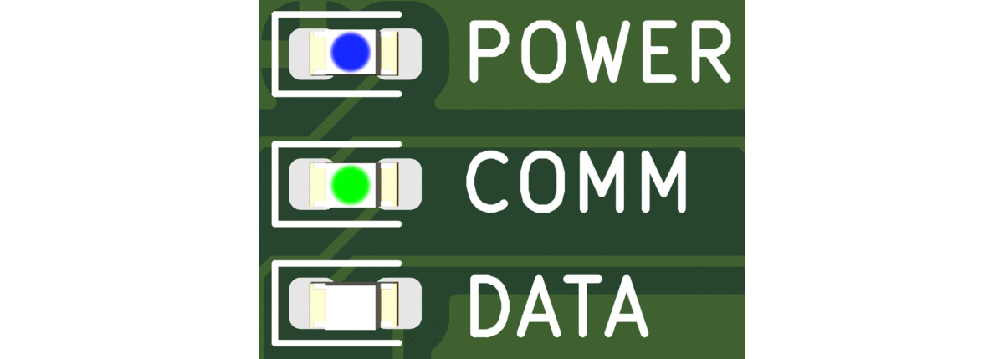
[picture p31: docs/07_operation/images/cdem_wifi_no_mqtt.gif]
CDEM WiFi - No MQTT


If all goes well and the MQTT broker can be reached, the communication LED should turn solid green.

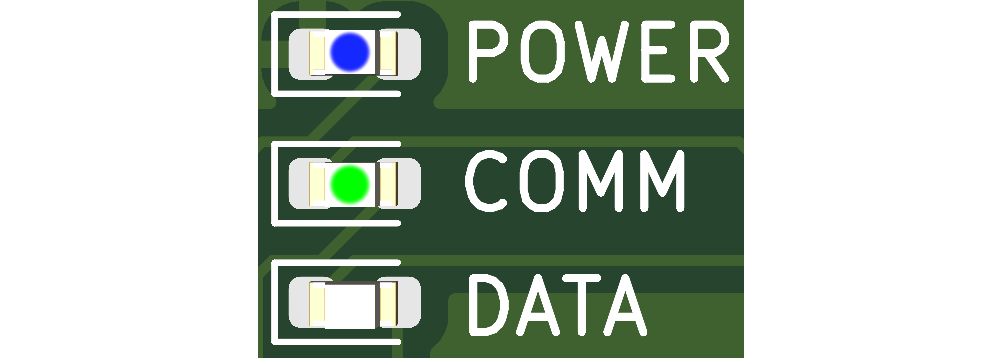
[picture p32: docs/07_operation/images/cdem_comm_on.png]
CDEM Communications OK


## Meter Readout Status

While setting up the WiFi connection and trying to connect to the broker, the CDEM device will continue the boot process and initialize the digital meter. This is indicated by the data LED blinking rapidly (interval of about 500 milliseconds).

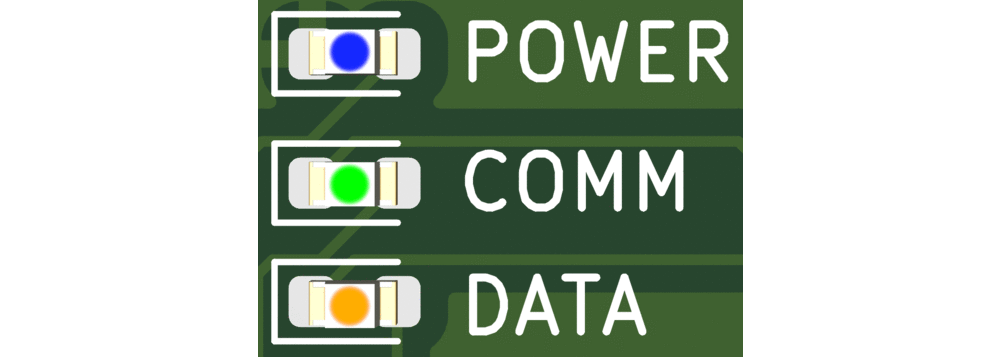
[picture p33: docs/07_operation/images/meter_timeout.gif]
Awaiting Meter Data


Once a datagram has been successfully read from the digital meter, the data LED should turn solid orange.

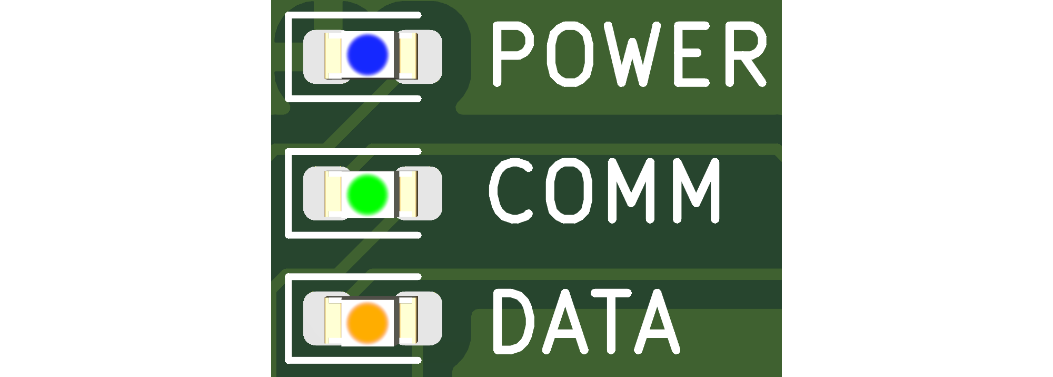
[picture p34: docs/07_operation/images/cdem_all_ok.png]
CDEM All Ok


If the data led keeps blinking orange and does not turn solid green after some time (depends on the readout interval you configured), then there please check the following:

* That the user ports of the Fluvius digital meter have been activated.
* That the cable is an RJ12 cable with 6 wires and is still ok. You may need to try out another cable.
* That the program jumper has been refitted in the correct position on your CDEM device.

<!-- TODO - Image here of the correct program jumper position -->

If neither of these help fixing the problem, please checkout the [Troubleshooting](/15_troubleshooting) section for more tips.

## Your Device at Work

If the device is fully operational and configured properly, then it will periodically:

* read a datagram from the P1 port of your Fluvius Digital Meter
* validate the received datagram
* decode the datagram to a human readable format
* publish that human readable format to your MQTT broker

In this case all three LEDs on the device should be lit continuously.

CDEM All Ok

## Your Data

Once the data has been published to your MQTT broker, it will be available in the topic you configured (default `iot/myhome/cdem`). Each data parameter will be published on a sub-topic of this parent topic as a simple floating point or integral value:

| Sub-topic | Value Type | Description | Unit |
| :---: | :---: | :---: | :---: |
| `consumption_high_tarif` | Floating Point | Cumulated electricity consumption (high tariff) | kWh |
| `consumption_low_tarif` | Floating Point | Cumulated electricity consumption (low tariff) | kWh |
| `production_high_tarif` | Floating Point | Cumulated electricity production (high tariff) | kWh |
| `production_low_tarif` | Floating Point | Cumulated electricity production (low tariff) | kWh |
| `total_power_consumption` | Floating Point | Instantaneous consumption over all phases | kW |
| `total_power_production` | Floating Point | Instantaneous production over all phases  | kW |
| `actual_voltage_l1` | Floating Point | Instantaneous voltage L1 | V |
| `actual_voltage_l2` | Floating Point | Instantaneous voltage L2 | V |
| `actual_voltage_l3` | Floating Point | Instantaneous voltage L3 | V |
| `actual_current_l1` | Floating Point | Instantaneous current L1 | A |
| `actual_current_l2` | Floating Point | Instantaneous current L2 | A |
| `actual_current_l3` | Floating Point | Instantaneous current L3 | A |
| `l1_power_production` | Floating Point | Instantaneous active power production L1 | kW |
| `l2_power_production` | Floating Point | Instantaneous active power production L2 | kW |
| `l3_power_production` | Floating Point | Instantaneous active power production L3 | kW |
| `l1_power_consumption` | Floating Point | Instantaneous active power consumption L1 | kW |
| `l2_power_consumption` | Floating Point | Instantaneous active power consumption L2 | kW |
| `l3_power_consumption` | Floating Point | Instantaneous active power consumption L3 | kW |
| `actual_tarif` | Integral | Tariff indicator (1=high, 2=low) | |
| `gas_meter_m3` | Floating Point | Total gas consumption | m^3 |

::: tip Different Readout
Do note that not all parameters may be available for your setup in your case. If you do not have a digital gas-meter, that information will not be available. You may also see only a single phase output if your home only uses a single phase.
:::

An all-in-one JSON representation will also be published in the subtopic `payload`. Below is an example of a real-life setup:

```json
{
   "actual_current_l1": 3.6,
   "actual_tarif": 1,
   "actual_voltage_l1": 227.3,
   "consumption_high_tarif": 716.568,
   "consumption_low_tarif": 649.135,
   "gas_meter_m3": 961.33,
   "l1_power_consumption": 0,
   "l1_power_production": 0.765,
   "production_high_tarif": 224.063,
   "production_low_tarif": 112.645,
   "total_power_consumption": 0,
   "total_power_production": 0.765
}
```

This allows for much easier processing using a custom application or for example NodeRED.

Using a tool such as [MQTT Explorer](http://mqtt-explorer.com/), you can easily take a look at it and check if the data is coming trough.

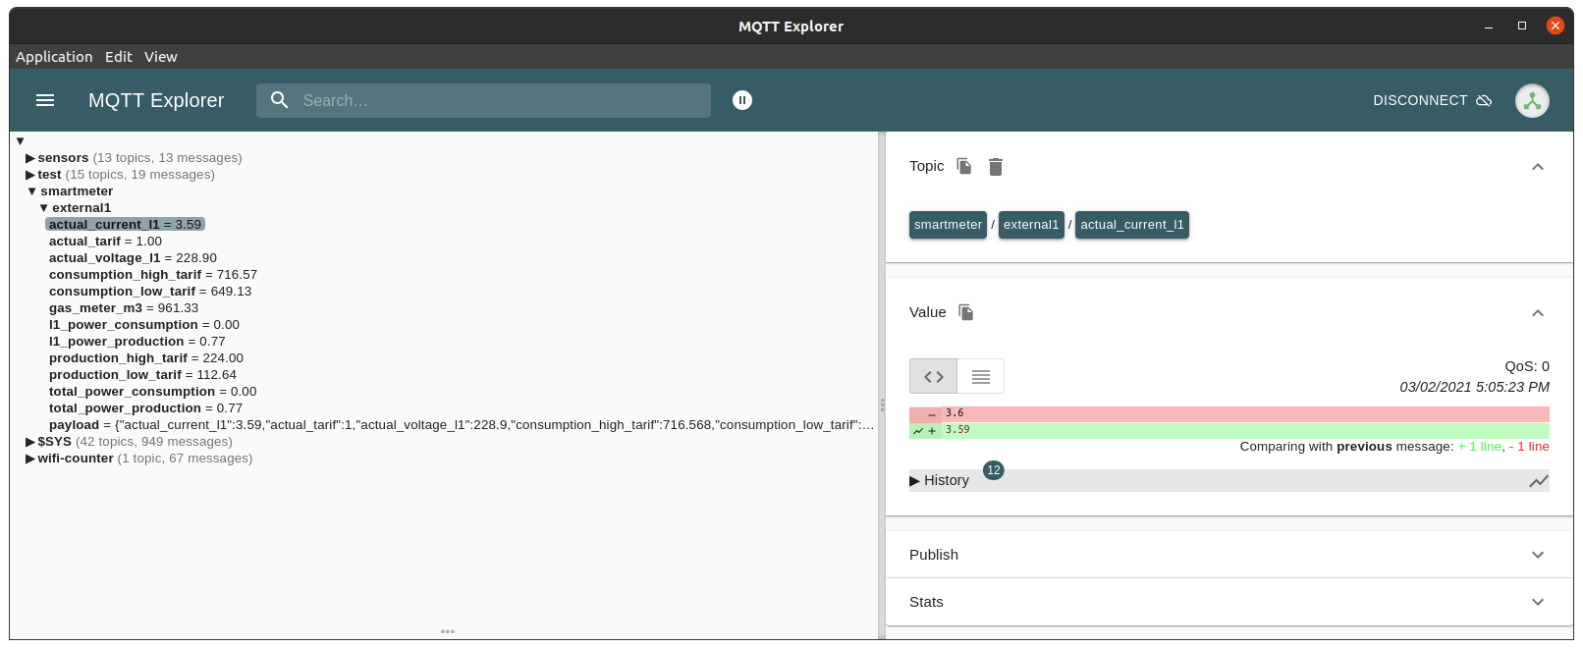
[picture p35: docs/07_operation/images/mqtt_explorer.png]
MQTT Explorer


### Statistical Information

Next to the meter data, the device will also periodically send some statistical information in JSON format on the subtopic `stats`:

```json
{
  "decoded": 41887,
  "timeouts": 0,
  "published": 41887,
  "crcerrors": 0,
  "uptime": "4d 21h 58m 16s 70ms"
}
```

The following information is included in this payload:

* `decoded`: the number of successfully decoded datagrams.
* `timeouts`: the number of times the meter timed out while receiving data.
* `published`: the number of datagrams that have been scheduled for publishing.
* `crcerrors`: the number of crc error checks that have occurred when validating the datagrams.
* `uptime`: the time the device has been up and running.

### Device Details

When the device has booted successfully it will also send a one time device details message in JSON format on the subtopic `announce`:

```json
{
  "ip": "xxx.xxx.xxx.xxx",
  "mac": "XX:XX:XX:XX:XX:XX",
  "lib-version": "v1.1.0",
  "pcb-version": "v4.0"
}
```

The following information is included in this payload:

* `ip`: the local IP address of the device.
* `mac`: the MAC address of the WiFi interface of the device.
* `lib-version`: the version of the `connected-digital-energy-meter` library the firmware is using.
* `pcb-version`: the version of the PCB hardware used for your CDEM device.

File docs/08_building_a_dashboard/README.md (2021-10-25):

# Building a Dashboard

Once your meter data reaches the MQTT broker it can basically be coupled to anything. Think [Home Assistant](https://www.home-assistant.io/), [openHAB](https://www.openhab.org/), [Node-RED](https://nodered.org/), [Grafana](https://grafana.com/), ... and if you know you way around any programming languages, chances are there is an MQTT library available.

In this chapter we'll describe the process of setting up a Grafana dashboard. No programming knowledge is required, it just takes some basic configuration and you'll see your telemetry flash by in no time.

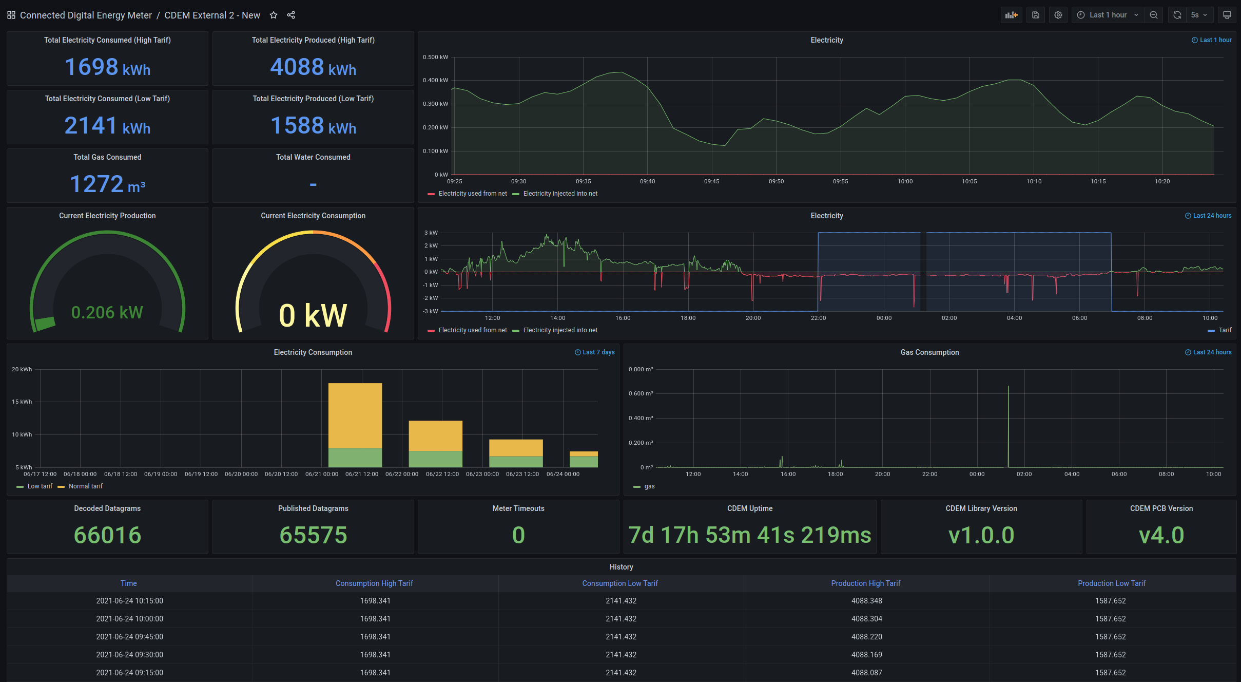
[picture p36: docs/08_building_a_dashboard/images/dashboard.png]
Grafana Dashboard


Because this setup should be running at all times, you will need a device to host the services we'll be setting up. This can be a PC, NAS or for example a Raspberry Pi. The services we will be setting up include [InfluxDB](https://www.influxdata.com/), [Node-RED](https://nodered.org/) and [Grafana](https://grafana.com/).

## Overview

For demonstrational purposes we'll provide a setup example on how to build a permanently available Grafana dashboard hosted on a Raspberry Pi device. Since the setup will not be needing a lot of processing power, the Raspberry Pi is actually perfect for this.

::: warning Raspberry Pi 4
This setup has only been tested with a Raspberry Pi 4 with 4GBs of memory. While it may work on an older Raspberry Pi, or a Raspberry Pi 4 with less memory, this has not been tested by us.
:::

In order to setup a nice Grafana dashboard, we will need some additional services. An overview of all the services is shown in the next diagram.

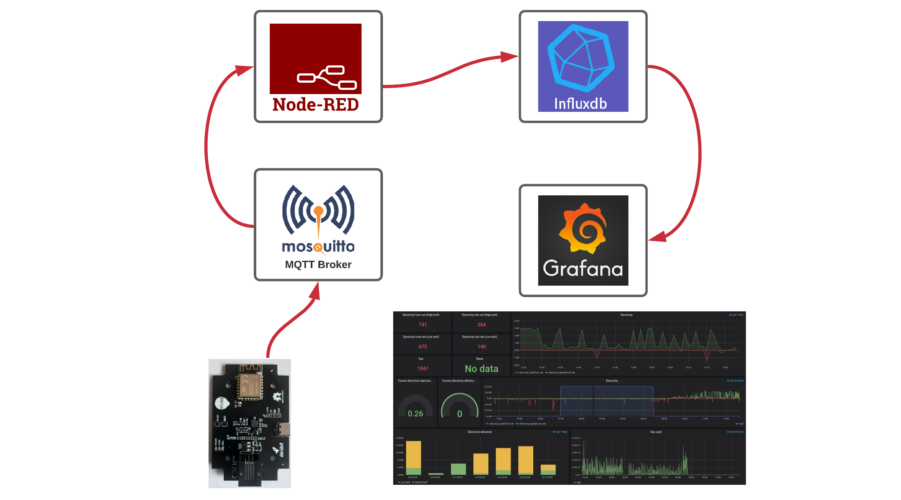
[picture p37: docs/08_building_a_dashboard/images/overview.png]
Overview


Basically, when the meter data reaches the **MQTT broker**, its no more than data from a given point in time. To create historical graphs we need some sort of storage. This is where **InfluxDB** comes in. Its a light-weight and proven time-series database. Ideally for storing our timestamped data.

Mosquitto (the MQTT broker) however, does not know how to talk to InfluxDB. This is the job of **Node-RED**, which acts as a connector from MQTT to InfluxDB. All data published to the MQTT broker is received by a Node-RED flow that does some minimal processing and then sends it to the InfluxDB.

Once this is setup, the data is safely stored inside the InfluxDB and its time to make the data visually available. This is where **Grafana** comes into play. Grafana is an analytics and interactive visualization web application. Basically, a dynamic and highly configurable dashboard generator.

All these tools are open source and can be used freely of charge.

If you are familiar with Linux / Docker and have a NAS or server running at home, you can actually skip the rest of this chapter and just use docker and docker compose to get a full working setup. Just checkout the [Docker Compose](/11_docker_compose) chapter.

## Updating your System

First make sure everything is up to date. This could take a while, especially on a new Raspberry Pi:

```bash
sudo apt update
sudo apt upgrade -y
```

## Installing Node-RED

The installation instructions for Node-RED on a Raspberry Pi can be found on the website of [Node-RED](https://nodered.org/docs/getting-started/). Just pick the *Raspberry Pi* tutorial and follow it carefully. Make sure Node-RED is working before continuing.

::: tip Node-RED Tutorials
If this is your first interaction with Node-RED, feel free to play around a bit. There are some great [tutorials](https://nodered.org/docs/tutorials/) available on their website. YouTube also has some nice videos on the subject. 
:::

## Installing InfluxDB

To be able to install InfluxDB on the Raspberry Pi, we will first need to add the repository key to APT. Adding the key will allow the package manager on Raspbian to search the repository and verify the packages its installing.

```bash
wget -qO- https://repos.influxdata.com/influxdb.key | sudo apt-key add -
```

Now that the InfluxDB repository key has been installed to the Raspberry Pi, we will need to go ahead and add its repository to the sources list.

```bash
source /etc/os-release
echo "deb https://repos.influxdata.com/debian $(lsb_release -cs) stable" | sudo tee /etc/apt/sources.list.d/influxdb.list
```

With the repository added, we now need to go ahead and update the package list again. This has to be done so that the APT package manager also searches the repository that we just added for packages.

```bash
sudo apt update
```

Now your system is ready to install InfluxDB:

```bash
sudo apt install -y influxdb
```

Once finished, start the InfluxDB service and also make sure that it starts when the Raspberry Pi boots:

```bash
sudo systemctl unmask influxdb.service
sudo systemctl start influxdb
sudo systemctl enable influxdb.service
```

### Creating a Database

You should now be able to run the `influx` client and create a new database called `home`. Since our InfluxDB instance will only be accessible locally, we create a single admin user called `grafana`.

First start the InfluxDB client:

```bash
influx
```

You are now presented with a terminal that will accept valid influx commands.

::: output
<pre>
Connected to http://localhost:8086 version 1.8.4
InfluxDB shell version: 1.8.4
> 
</pre>
:::

Start by creating a database using the following commands:

```
create database cdem
use cdem
```

::: output
<pre>
Using database cdem
</pre>
:::

Next create a `grafana` user with a strong password.

```
create user grafana with password 'strong_password_here' with all privileges
grant all privileges on cdem to grafana
```

You can always double check if all went well by using the commands `show users` and `show databases`.

Type `exit` to leave the influx client.

### Installing Grafana

As was required with InfluxDB, for Grafana we also need to add the APT key so the packages can be authenticated:

```bash
wget -q -O - https://packages.grafana.com/gpg.key | sudo apt-key add -
```

Add the Grafana APT repository:

```bash
echo "deb https://packages.grafana.com/oss/deb stable main" | sudo tee -a /etc/apt/sources.list.d/grafana.list
```

Now you are ready install Grafana:

```bash
sudo apt-get update
sudo apt-get install -y grafana
```

Grafana is now installed, but not yet running. To make sure Grafana starts up even if the Raspberry Pi is restarted, we need to enable and start the Grafana Systemctl service. Proceed by enabling and starting the Grafana server:

```bash
sudo systemctl unmask grafana-server.service
sudo systemctl enable grafana-server
sudo systemctl start grafana-server.service
```

Grafana is now running on the machine and is accessible from any device on the local network.

Open a browser and go to `http://<raspberry_ip_address>:3000`, where the IP address is the address that you used to connect to the Raspberry Pi earlier. You’re greeted with the Grafana login page.

Log in to Grafana with the default username `admin`, and the default password `admin`. **Change the password** for the `admin` user when asked.

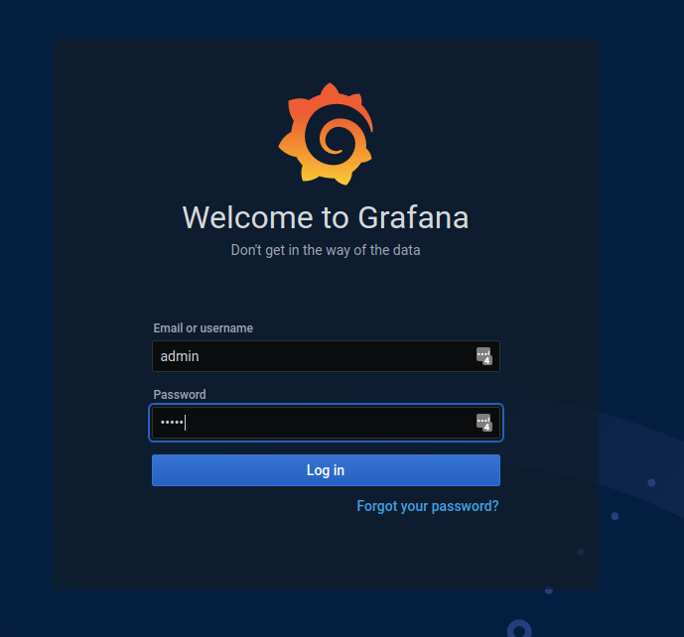
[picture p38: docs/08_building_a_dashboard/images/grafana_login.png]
Grafana Login


Congratulations! Grafana is now running on your Raspberry Pi. If the Raspberry Pi is ever restarted or turned off, Grafana will start up whenever the machine regains power.

## Adding InfluxDB to Grafana

With InfluxDB and Grafana running, we can stitch them together. Log in to your Grafana instance and navigate to `Data Sources` by clicking the configuration gear icon ⚙️ on the left. Hit the `Add data source` button and look for the `InfluxDB` data source below `Time series Databases`.

Use `CDEM` as the name of the data source.

As we are running both services on the same device, set the URL to `http://localhost:8086`, where `8086` is the default port InfluxDB is running on.

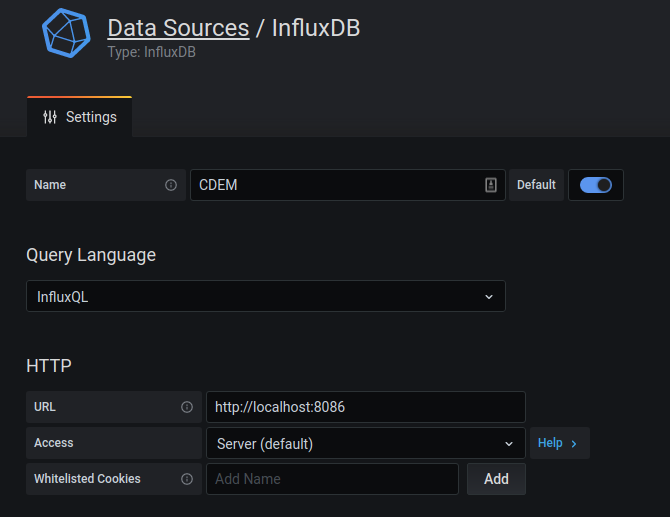
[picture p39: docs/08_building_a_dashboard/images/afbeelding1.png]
InfluxDB Data Source


Now scroll down and set the database to `cdem`, the user to `grafana` and also fill in the password that you used for the `grafana` user with InfluxDB.

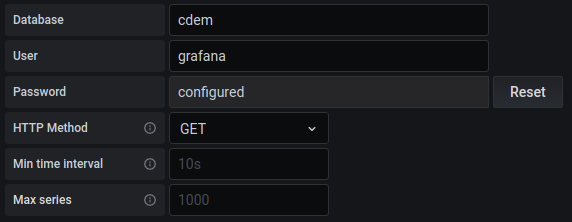
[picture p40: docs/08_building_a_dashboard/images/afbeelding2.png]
InfluxDB Credentials


That’s all that is required.

Now go ahead and hit `Save & Test` to allow Grafana to test the connection to the database and if successful save it.

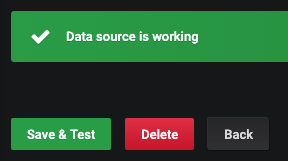
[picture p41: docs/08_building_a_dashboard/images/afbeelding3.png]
Save and Test


## Node-RED Flow

The next step is to setup a Node-RED flow that will subscribe to our MQTT topic on which the meter is being published and store its data in the InfluxDB.

Start by opening another browser tab/window and navigating to `http://<raspberry_ip_address>:1880`, where `1880` is the default port on which Node-RED is exposed.

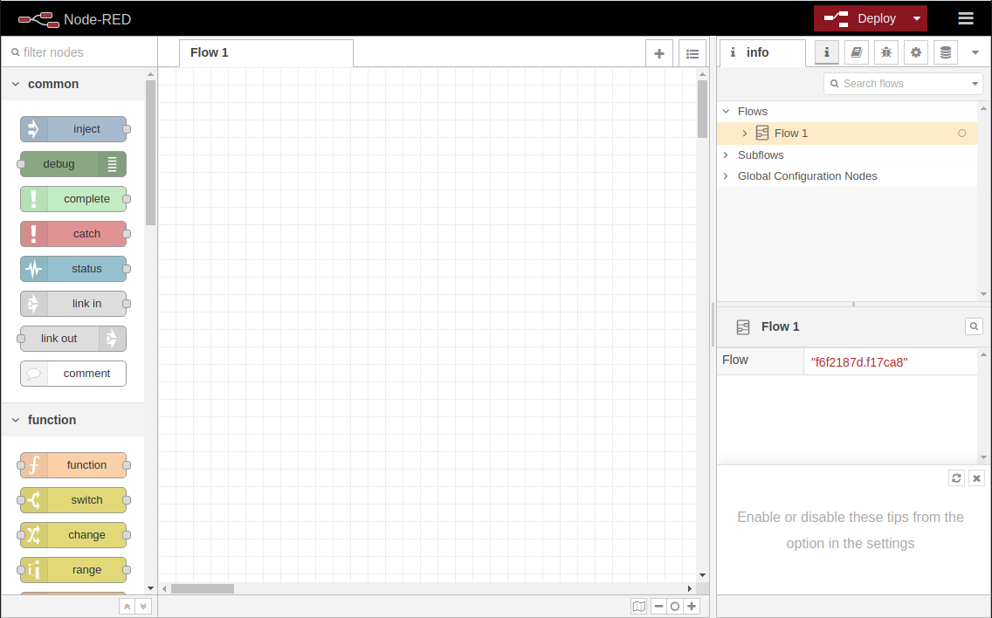
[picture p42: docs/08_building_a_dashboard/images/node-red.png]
Node-RED


Before we can continue, we'll need to install the `node-red-contrib-influxdb` module to allow Node-RED to communicate with InfluxDB. Click the hamburger menu icon in the top right corner and navigate to `Manage palette`. Select the `Install` tab and search for `influxdb`

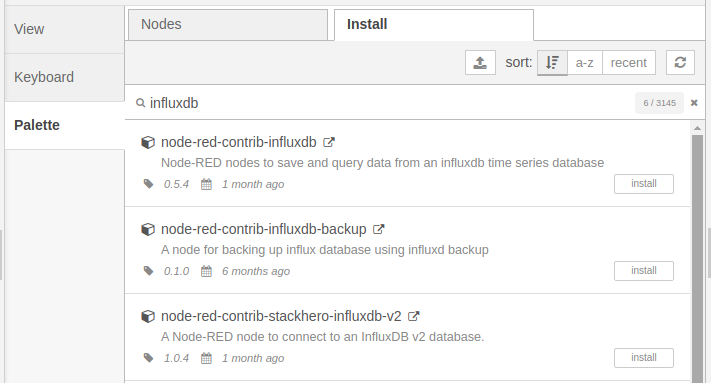
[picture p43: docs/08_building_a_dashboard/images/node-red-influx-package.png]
InfluxDB Package


Select the `node-red-contrib-influxdb` module and click the `Install` button on the right. Select `Install` when a popup appears. If all went well, the module should be tagged as `Installed`.

Next [download](/files/cdem_node_red.json) our Node-RED flow. This flow will subscribe to the topic that contains the data of your Connected Digital Energy Meter from the MQTT broker and push it to your InfluxDB.

Import the flow into Node-RED by clicking the hamburger menu in the top right and selecting `Import`. Click the button `select a file to import` and select the `cdem_node_red.json` file you just downloaded. Once loaded, click the `Import` button.

You should now have a new flow tab on top called `CDEM`. Click to tab to show the flow.

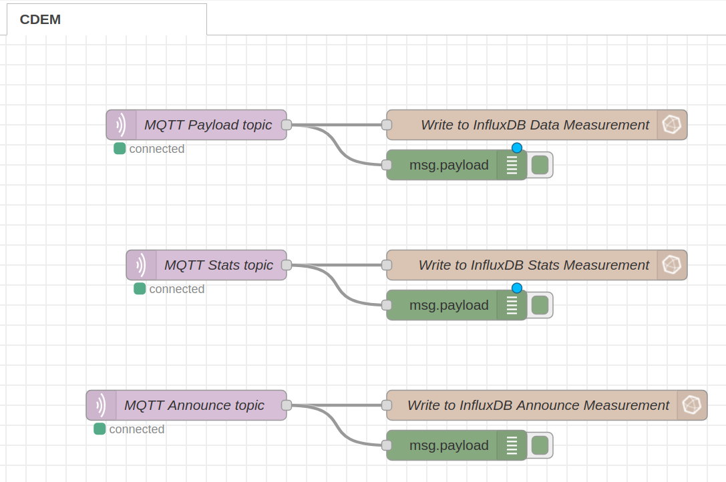
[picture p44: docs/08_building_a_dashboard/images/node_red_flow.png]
Node-RED CDEM Flow


If you changed the factory default MQTT topic when you configured the CDEM device, you will need to reflect this change in this flow. Double click the `MQTT Payload topic` node in the flow and configure the correct `Topic`. **Do make sure to leave the `/payload` topic intact at the end.**

You may also need to change your broker settings when your MQTT broker is not running on the Raspberry Pi itself. You can configure your broker by clicking the pencil icon next to the `Server` setting. Click `Done` when finished.

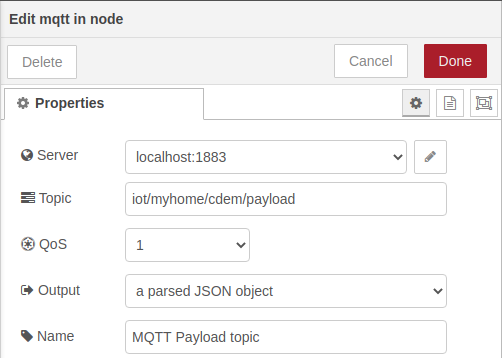
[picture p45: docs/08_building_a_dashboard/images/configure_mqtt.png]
Configuring MQTT


::: warning InfluxDB Database
In case you did not use the same database name for InfluxDB as we did, `cdem`, you will also need to configure the InfluxDB server to make use of the correct database. Double click any of the InfluxDB nodes on the right and hit the pencil icon next to the `Server` setting. You can now change the `Database` name. Hit `Update` and `Done` when finished.
:::

Once you are ready, hit the big red `Deploy` button in the top right corner.

You can check the data coming in by clicking the small bug icon in the top right. That will open up the debug panel and print out the debug message.

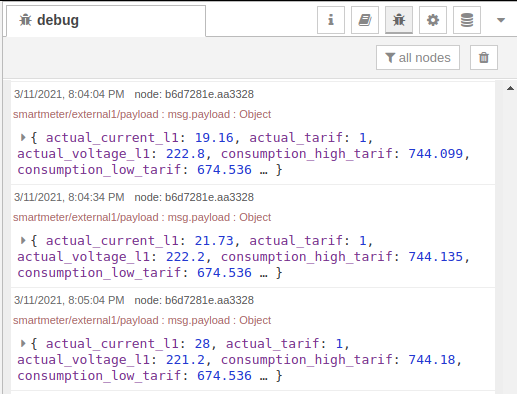
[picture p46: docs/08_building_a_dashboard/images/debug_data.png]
Debug Data


## Grafana Dashboard

Now is the time we all have been waiting for. A visual representation of the Connected Digital Energy Meter data.

Start by [downloading the template dashboard](/files/grafana_dashboard.json) we build for Grafana.

Now open Grafana in your browser and navigate to the four squares `Dashboards` icon on the left and select `Manage`. Select the `Import` button in the top right,

Next click the `Upload JSON file` button and select the template dashboard file you just downloaded.

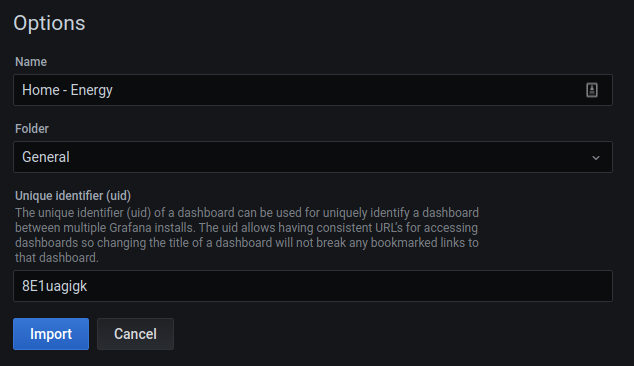
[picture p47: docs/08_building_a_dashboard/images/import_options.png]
Import Options


You can probable leave the options as is. Click `Import` to finish the import.



<!-- TODO - Update the screenshot with the new dashboard once we have some data -->

::: tip 📩 Download CSV / Excel History
If you wish to download a file containing the history of your total consumption and production values, you can achieve this by selecting the `History` panel and navigating to `Inspect => Data`. There you will find the button `Download CSV`.
:::

## Interpreting the Dashboard

* In the electricity graphs you can detect spikes in delivery and start investigating the cause. The next step is to check if you can either make improvements or redirect this energy usage to a low tarif period.

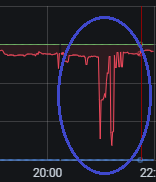
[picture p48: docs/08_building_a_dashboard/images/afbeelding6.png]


* You can also evaluate your consumption in low and normal tarif to make decisions about when to use the large energy consuming appliances.

* If you have a form of domotics you could use the tarif indicator to shut down some of your appliances (freezer, boiler, ...) while in normal tarif. You can do this by adding some automation with Node-RED.

## Future

Once all the MQTT data from your Connected Digital Energy Meter is redirected to your InfluxDB you can add extra's like:

* Power info from your Solar Panel Inverter
* Outdoor and indoor temperature
* Your central heating system

Of course is visualisation of the energy value's only the first step in energy effeciency.
The next step will be to use that data to make your home energy consumption better.
See chapter [Energy Efficiency](/12_energysavings) for more information on that.

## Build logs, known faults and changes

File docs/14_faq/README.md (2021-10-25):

# Frequently Asked Questions

<!-- ---------------------------------------------------------- -->

::: details Should I use a public MQTT broker?
It is our personal opinion that it is **better practice to keep the MQTT data local instead of in the cloud**. It's sensitive data that one could use to determine when nobody is at home. So we recommend not using a public MQTT broker.
:::

<!-- ---------------------------------------------------------- -->

::: details How can I use this device to save on my energy bill?
* For starters you can use the output of your production (if you have solar pannels) and your consumption of energy to detect when you use most energy and at what tarif you are consuming energy. If you can figure out what devices or actions cause that energy usage you can adjust your habits so you use energy when it is least expensive for you.
* If you have a domotics system you can automate the above and cut the power to certain appliance when the energy price is high and your production is low.

More info is provided in the chapter [Energy Efficiency](/12_energysavings).
:::

<!-- ---------------------------------------------------------- -->

::: details Why is my CDEM rebooting unexpectedly?
When you notice that your CDEM device is rebooting unexpectedly from time to time, then it may well be that the **power supply of your Fluvius Meter is insufficient**. In this case we advice to use an external USB power supply (such as a smartphone adapter) to power your CDEM device.

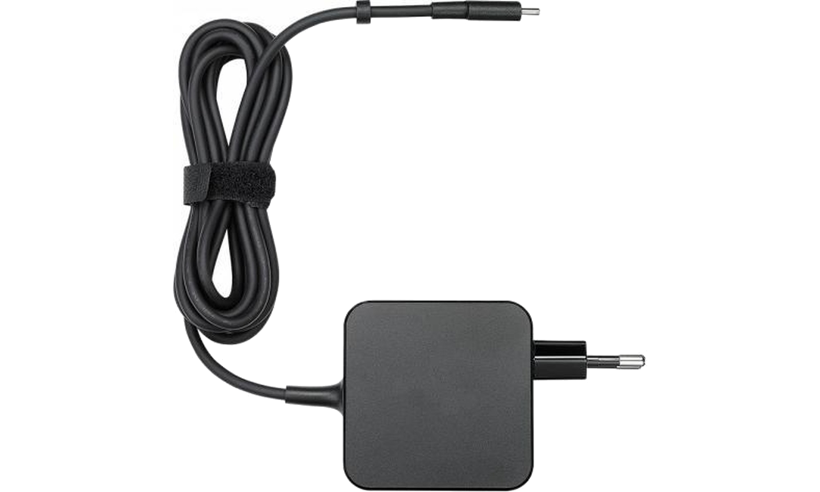
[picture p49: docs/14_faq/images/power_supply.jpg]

:::

<!-- ---------------------------------------------------------- -->

::: details Why does the DATA led keep blinking orange?
When the DATA led keeps blinking orange there is a problem with the communication between your CDEM device and the Fluvius Meter. This can have several causes:

1. **The Fluvius user ports are not activated (anymore).** If this is a fresh setup you may need to wait a few days longer for the ports to become active. If this was a functioning setup, you need to check the activation status of the user ports on the digital meter. There should be a small arrow above the `GP`. If not please re-activate the user ports. Check the [Activating the Fluvius Meter Port](/06_connect/#activating-the-fluvius-meter-port) section for more information.

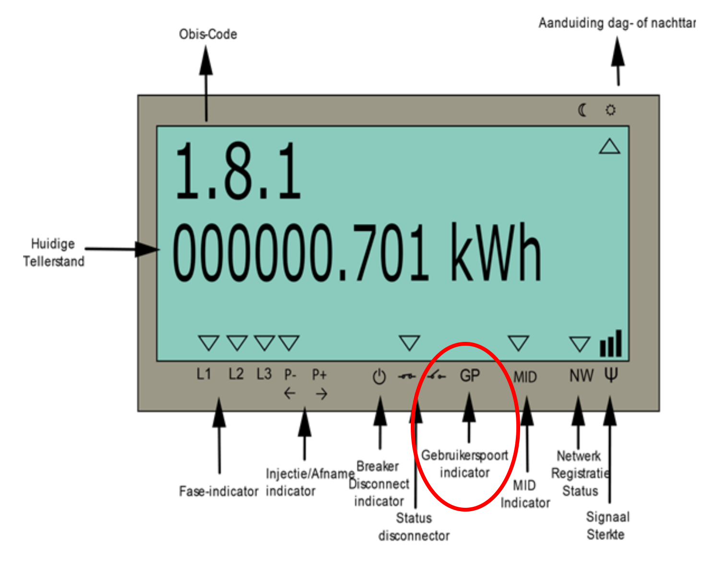
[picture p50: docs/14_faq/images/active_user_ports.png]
Active User Ports


2. **The RJ12 cable is faulty** and may need to be replaced.
3. **The program jumper is not placed (correctly)** on your CDEM device. Checkout the [Compile and Configure the Firmware](/03_firmware/#compile-and-upload-the-firmware) section for more information.
:::

<!-- ---------------------------------------------------------- -->

::: details Why am I getting errors when I'm trying to upload the firmware?
Make sure to check the following things when uploading the firmware to the CDEM device:

1. Is the device connected via USB-C to your computer?
2. Have you selected the correct COM-port in Arduino IDE?
3. Is the jumper placed in the program position? Checkout the [Compile and Configure the Firmware](/03_firmware/#compile-and-upload-the-firmware) section for more information.

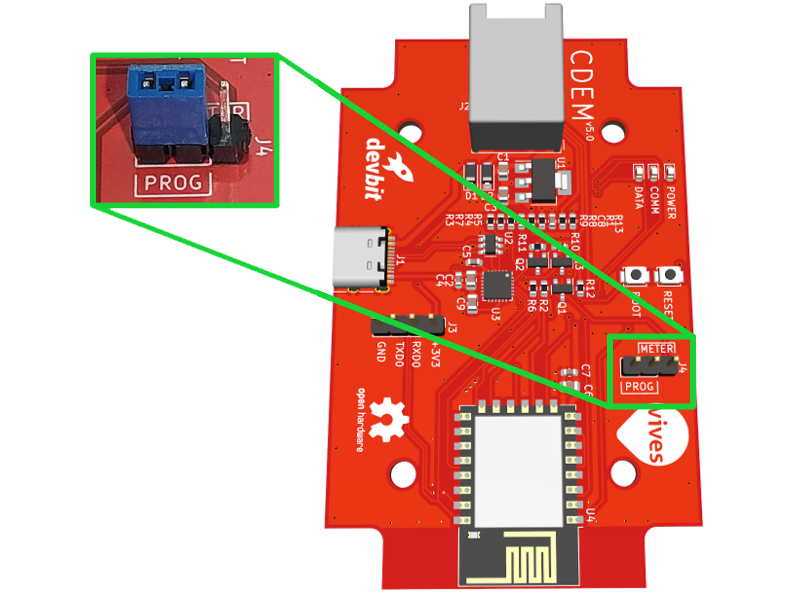
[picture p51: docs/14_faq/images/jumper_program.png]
Program Jumper


:::

<!-- ---------------------------------------------------------- -->

::: details Can I see if my user ports are activated?
Yes you can. Go to Fluvius digital meter and hit the lime green user button once. The display should become lit. A small arrow should be placed above `GP`. If not, than your user ports are not activated.

Active User Ports
:::

<!-- ---------------------------------------------------------- -->

::: details Why are the timeouts increasing?
If the timeouts counter in the `stats` topic is increasing, there might be a problem with the readout of the meter. This can have several causes:

1. **The Fluvius user ports are not activated (anymore).** If this is a fresh setup you may need to wait a few days longer for the ports to become active. If this was a functioning setup, you need to check the activation status of the user ports on the digital meter. There should be a small arrow above the `GP`. If not please re-activate the user ports. Check the [Activating the Fluvius Meter Port](/06_connect/#activating-the-fluvius-meter-port) section for more information.

Active User Ports

2. **The RJ12 cable might be faulty** and may need to be replaced.
3. **Is the jumper placed in the meter position**  on your CDEM device?

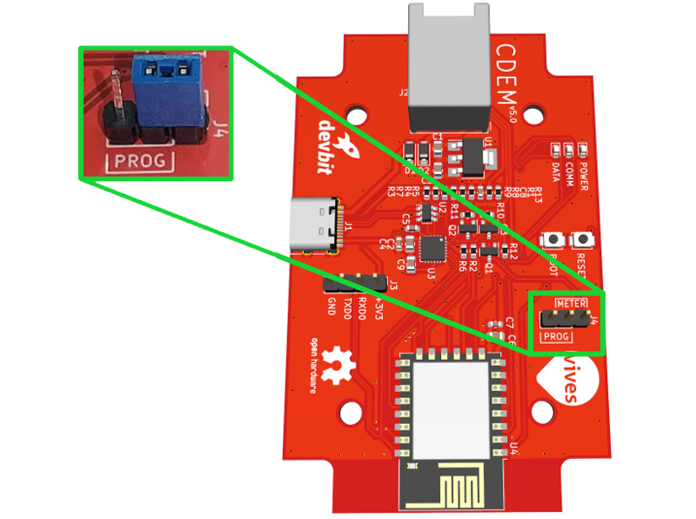
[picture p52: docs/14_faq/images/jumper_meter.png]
Meter Jumper


:::

<!-- ---------------------------------------------------------- -->

::: details Config page cannot be reached
If you get an error similar to `This site can't be reached` when trying to load the config page. Than check the following things:

* Is the COMM LED slowly blinking ? If not then the captive portal is not active. Reboot the device by unplugging it and plugging it back in.
* Are you connected to the CDEM-Config access point ? If not, then first connect to it.
* Did you disable your data-connection on your smartphone? If not, please do so.
* You may get this error if you are surfing to a URL that you have visited some time ago. Your smartphone is using it's DNS cache to resolve the URL. Try using another URL like for example [config.cdem.be](http://config.cdem.be).
:::

<!-- TODO - Redirect to correct sections -->

<!-- ---------------------------------------------------------- -->

::: details The device is not booting when attached to the meter
If the device works fine when attached to the computer but it is not booting when connected to the meter, there might be several causes:

1. Your cable is faulty or is actually an RJ11. Make sure the cable is ok and has 6 wires (RJ12) on both sides of the connector.
2. Your device may request more power than the meter can provide. This may happen when your WiFi access point is far away from the device. It may be necessary to add an external USB-C power adapter to the device (any smartphone adapter should be ok).
:::

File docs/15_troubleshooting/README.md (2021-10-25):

# Troubleshooting

TODO - Work in Progress

Reading the debug messages

::: details General troubleshooting
If your setup doesn't do the expeceted you can folow these problem detecting steps:

1. Are both led's on your CDEM both green? If not:
   
   - check the cable connecting your CDEM with your digital meter
   - check if you have a wifi connection
   - check if your mqtt broker is up and running

2. Is the data being published to your MQTT broker?

   - check with MQTT Explorer if the data is being published

3. Is your influxdb and grafana running?

   - check if your influxdb and grafana is up and running.

4. Are you connected to internet?

   - Check if you have internet connection in your network. If not, it is possible that your network is unable to reach a DNS server and therefore has trouble locating your devices.
:::

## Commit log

2021-01-11 started working on the guide
    [bottom.stl, top.stl]
2021-01-14 added installing Arduino IDE and uploading the firmware. This closes #8
2021-01-19 Create landing page for the docs. This closes #10
2021-01-19 Add list of requirement components for the PCB and CDEM. This closes #4
2021-01-19 placing todo's in comment
    [bottom.stl, top.stl]
2021-01-19 Add pin headers to component list
2021-01-20 faq added
    [bottom.stl, top.stl]
2021-02-16 Change Node-red flow and added Grafana flow
2021-02-25 Add photos of the different components required to assemble the PCB
2021-02-26 Refactor the device configuration chapter
2021-03-01 Add some images and gifs of the status leds
2021-03-01 Fix the status leds gifs by using https://gifmaker.me/
2021-03-01 added flowchart of firmware
2021-03-02 Document the operation of the device, different states and the published data
2021-05-26 update to v2 of pcb
2021-05-26 Switch connect and configure chapters
2021-05-28 added solar prediction and some images of the new pcb
2021-06-04 added pcb versions and some updates
2021-06-21 Fix some images and add decent GIFs of device status
2021-06-21 Update the operation chapter to reflect the new PCB and firmware
2021-06-21 Update node-red flow to make use of single measurement
2021-06-21 Update dashboard to make use of single measurement and display device stats
2021-06-21 Fix lib version and pcb version disappearing after some time
2021-10-27 Update image of latest pcb
